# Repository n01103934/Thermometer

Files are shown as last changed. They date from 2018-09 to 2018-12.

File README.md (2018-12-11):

# Build Instructions

# Introduction
My project I am working with deals with reading temperature data from a temperature sensor. My sensor 
is called a TMP006 IR Temperature Sensor that can measure the temperature of any object without making direct contact with it.
It detects and absorbs the infrared energy from an object regardless of how hot or cold it is. I plan on storing 
my temperature data from my sensor to the Firebase database where all my data is stored. The reason why I chose this
project is because I was interested in the idea of reading an object's temperature data from the sensor just by pointing my finger
directly close to it. Here is a system UML diagram below to show you how my hardware will send data from my Raspberry Pi 3 to my database.
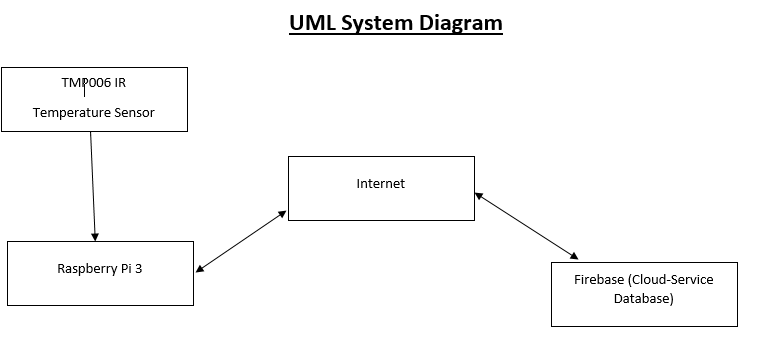
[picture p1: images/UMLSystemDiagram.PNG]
UML Diagram


# Bill of Materials/Budget
The total cost of my budget is $131.55 which is below the maximum limit of $150. I did not order any of my hardware materials online instead I went to local electronic stores such as Canada Computers and Creatron Inc. They had everything I needed in my budget including Raspberry Pi 3 kit, TMP006 IR Temperature Sensor, SD Card, USB to Ethernet Adapter, etc. I also included where I got my parts from the links in my budget. Here is a image below to show you my budget and all the materials I used for my project.
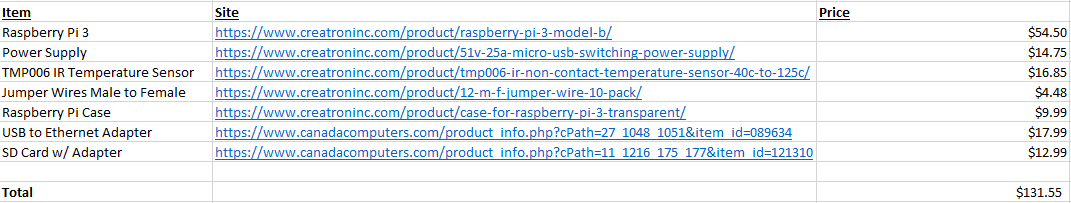
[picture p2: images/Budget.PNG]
Budget


# Time Commitment
The project did not take me long to complete because I got my parts ahead of time and started working on it as soon as possible.
However, their was still alot of time and commitment put in setting up my Raspberry Pi 3 and changing the default address to the
address you are assigned as well as reading data from the sensor. If you got all your materials then it would take you about 3 to 5 weeks to complete the project as long as you follow the steps of building it. Their are electronic stores that lucky have what you need such as Creatron Inc and Canada Computers. Once you acquired the parts start setting up your Raspberry Pi 3 which took almost a week at the lastest for me to set it up. After that then solder the header pins with the sensor to make a connection to it and the Raspberry Pi 3. Then, test the sensor and see if it can read data by running the python program for the sensor's library and it should be able to display the temperature readings on the output just by pointing finger close to the sensor. Overall, it took alot of time and commitment inorder to finish this project and put it all together for the next term.

# Mechanical Assembly
Before, you connect your sensor to Raspberry Pi 3 you need to get header pins in order for your Raspberry Pi 3 to detect it. I provided 
a link to show you where you could get them for your sensor incase you don't already have one.  
https://www.digikey.ca/product-detail/en/omron-electronics-inc-emc-div/XG8T-0231/XG8T-0231-ND/1829453?productid=1829453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

This open-sourced adafruit website will help you connect the TMP006 IR Temperature Sensor with the Raspberry Pi 3 or BeagleBone Black.
https://learn.adafruit.com/tmp006-temperature-sensor-python-library/hardware

Firstly, you need to connect a jumper wire from the 3.3V pin of the Raspberry Pi 3 to first pin(VCC) on my sensor. Secondly, the GND pin on Raspberry Pi 3 connects another jumper wire to the second pin(GND) of my sensor. After, connect a third jumper wire from SDA pin of Raspberry Pi 3 to the third pin(SDA) of my sensor. Then, the SCL pin of Raspberry Pi 3 connects with the fourth pin(SCL) of my sensor. The next link will give you information on how to change your sensor's default address which is 0x40 to another one ranging from 0x41 to 0x47. https://learn.adafruit.com/infrared-thermopile-sensor-breakout/assembly-and-wiring

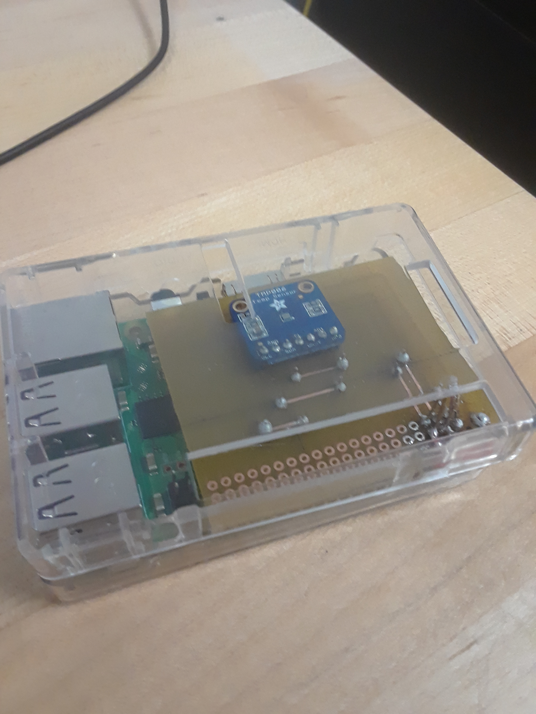
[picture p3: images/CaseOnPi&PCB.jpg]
PCB in Case


# PCB / Soldering
I made a fritzing file in my repository to create my own custom PCB just by following my breadboard and schematic
connections to do the same for the PCB. The file is called Thermometer Circuit Diagram.fzz in my github repository. 
https://github.com/n01103934/Thermometer

Here are images below to view my breadboard, schematic, and pcb diagrams for my project.
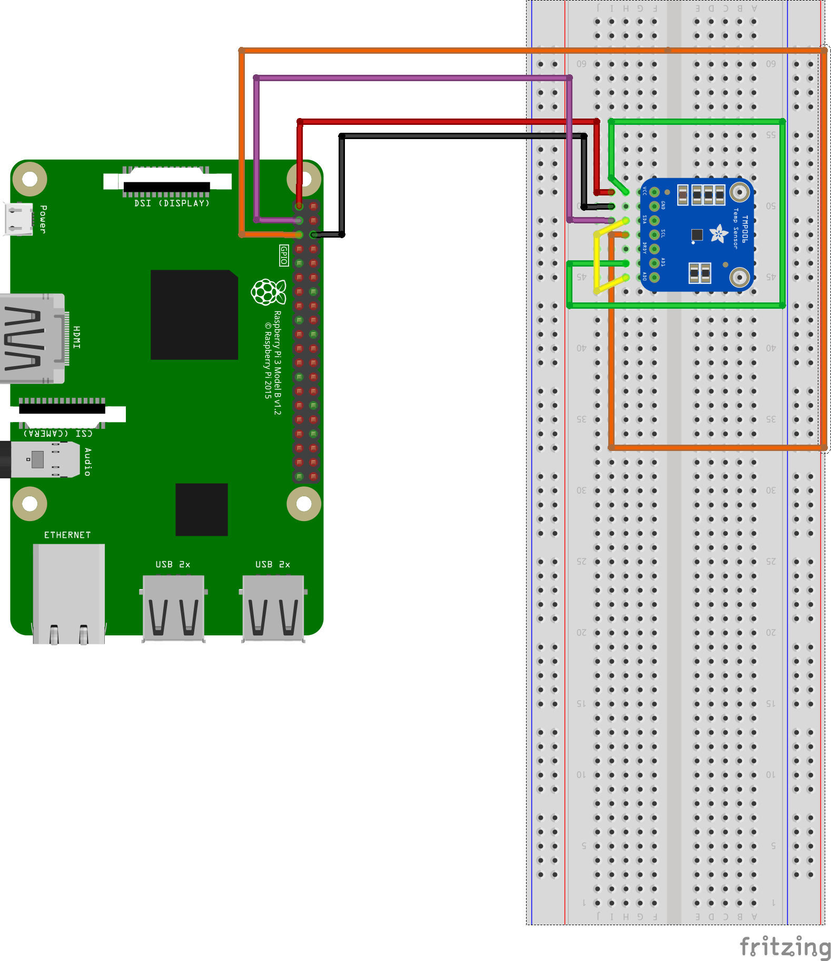
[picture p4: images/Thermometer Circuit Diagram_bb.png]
Breadboard

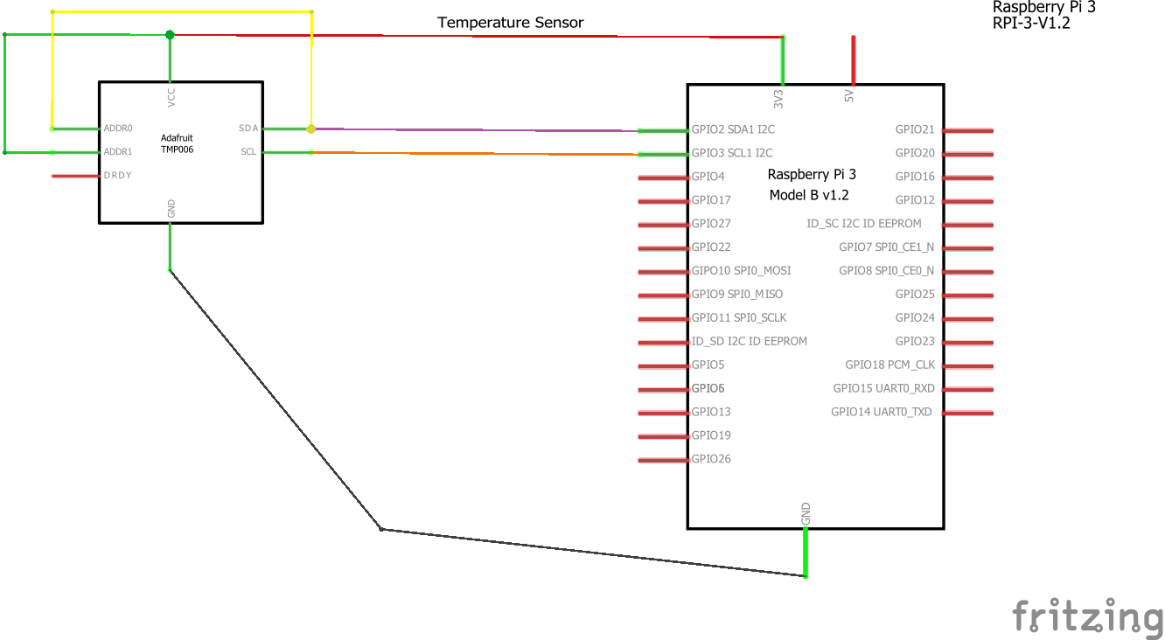
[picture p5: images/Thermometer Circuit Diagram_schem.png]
Schematic

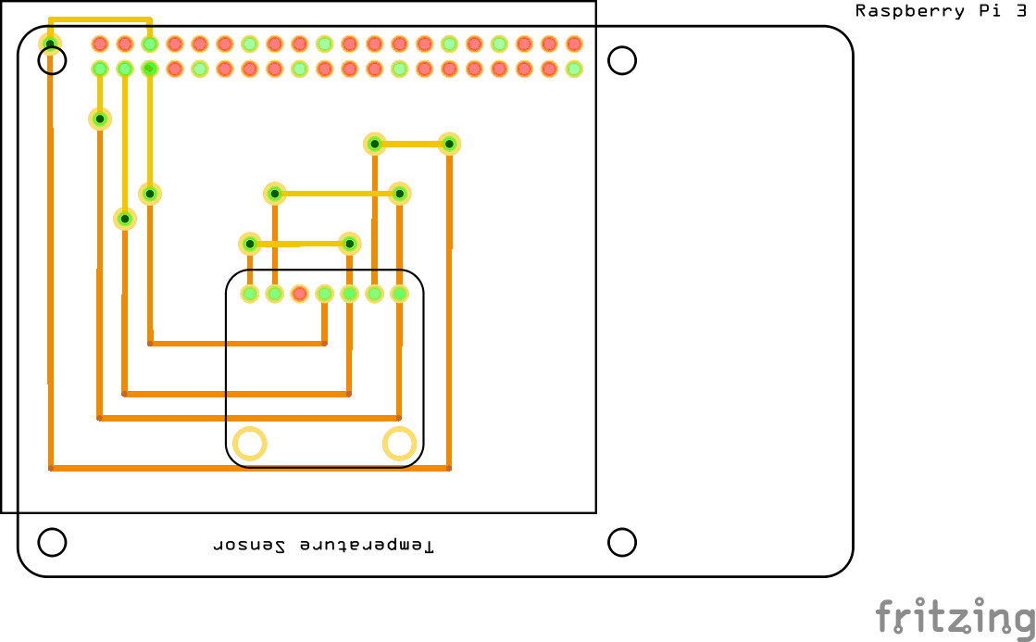
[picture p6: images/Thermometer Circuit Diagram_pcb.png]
PCB


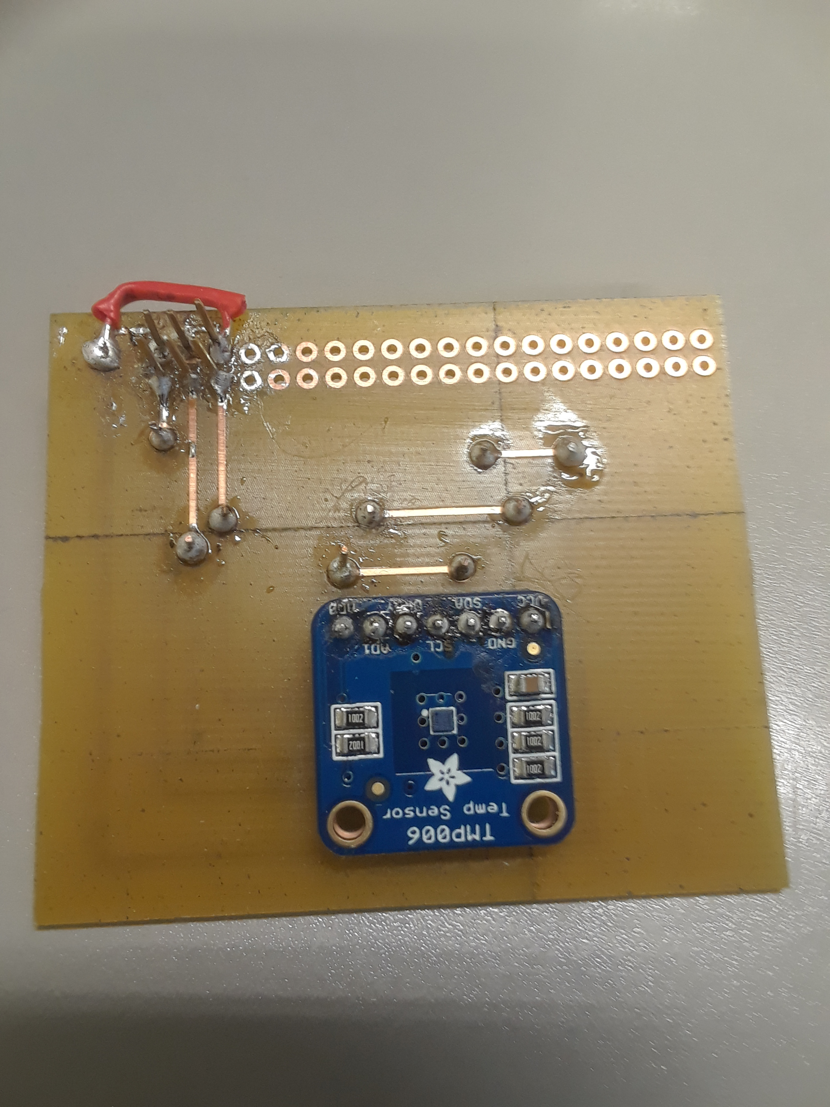
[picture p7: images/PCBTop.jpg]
PCB Top

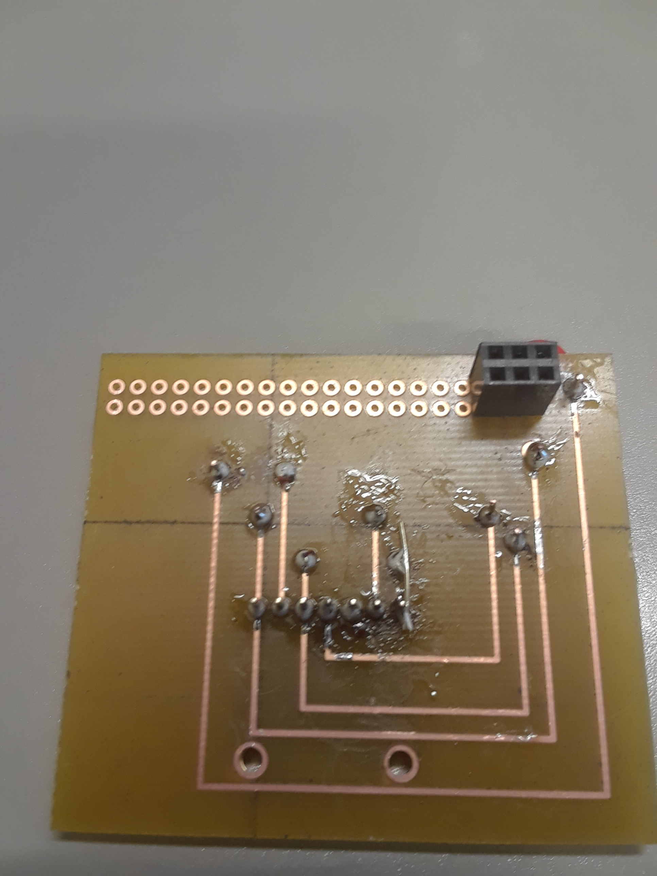
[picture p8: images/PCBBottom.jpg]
PCB Bottom


Additionally, I emailed the prototype lab my gerber files by exporting them from my fritzing project and got my board 
the next day. Then, I started soldering my via traces on my custom PCB and connected my header pins to the board. 
After, I soldered my header pins on sensor to my PCB board from the top to bottom and I connected the header socket to 
my board as well. I had to solder a wire connecting from the GND pin to my via trace connected to ground in order for my Raspberry Pi 3 to have a solid connection with my sensor. Finally, I connected the PCB to my Raspberry Pi 3, powered it on, ran the sudo i2cdetect -y 1 on cmd
terminal and I got my I2C address (0x46) displayed on the output for my sensor. 

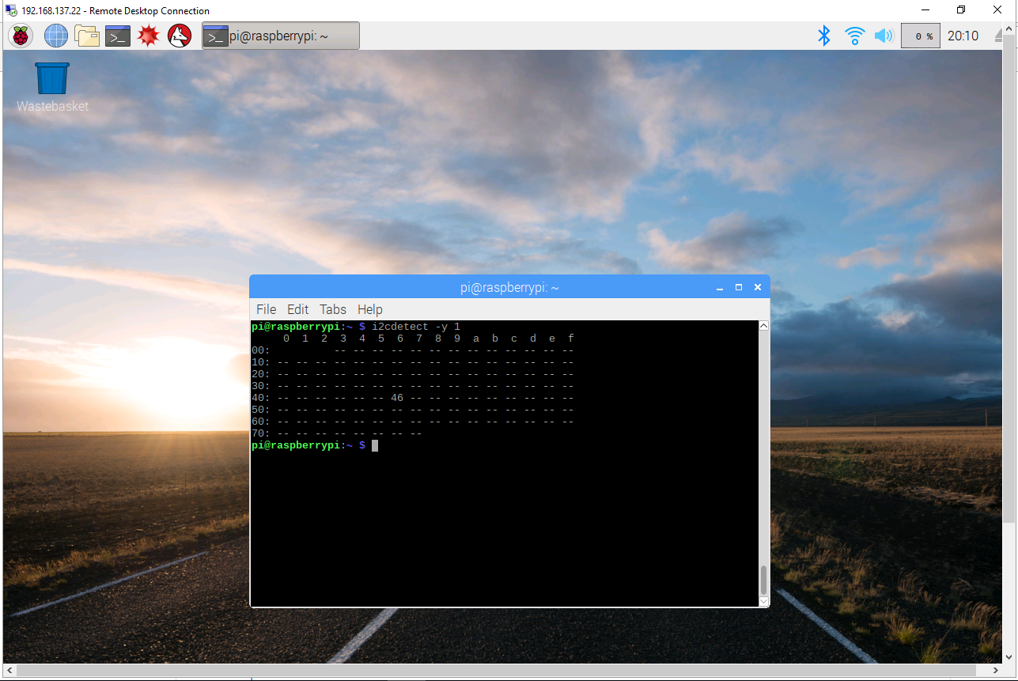
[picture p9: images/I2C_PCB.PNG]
I2COnPCB


# Power Up
First you need to download the operating system of Pi and format the micro SD card using the SD card reader included with 
the card to upload the Pi image to the Raspberry Pi 3. Here is a very useful blog that I followed step by step to upload my 
image to Raspberry Pi 3 as well as basic setup. https://github.com/six0four/StudentSenseHat/blob/master/cribpisdcard.md

Once you installed the operating system and got the image uploaded to Raspberry Pi 3, insert the SD card into the slot at the 
bottom of Pi, and boot it up with the power supply. If you are booting the Raspberry Pi 3 for the first time then you will have 
the option to change the default username and password to what ever suits you or you can leave it the same. The default username 
and password for every Raspberry Pi is always pi and raspberry unless a user changes it. Everything you need to know about the basic
setup of the Raspberry Pi is from the first link provided above just follow the instructions and your Pi should be ready. Some commands
to consider using for updating your Raspberry Pi 3 are sudo apt-get update and sudo apt-get dist-upgrade for installing packages to their latest versions for Pi. You need to make sure that I2C is enabled on the Raspberry Pi in order to use cmds like i2c detect for displaying the address of your sensor. In order to do that go to the Raspberry Pi configuration from start menu or type in terminal sudo raspi-config, then go to Interfaces and click on the I2C option to enable it if it hasn't already been enabled yet. 

Here is an image below to demonstrate me powering up my Raspberry Pi 3 with PCB connected to it.
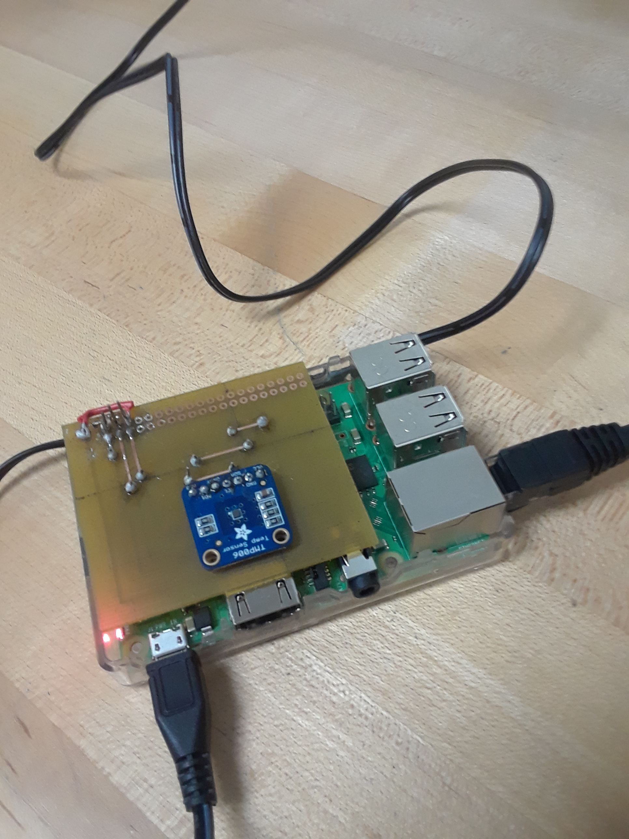
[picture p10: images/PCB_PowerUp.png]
PCB Powerup

 
# Unit Testing
In order to test whether or not the sensor is connected to the Raspberry Pi 3 properly you need to
open up a terminal on Pi and issue the command sudo i2cdetect -y 1 to list all the I2C addresses connected to the
Raspberry Pi 3. Here is an image below to show you my I2C address shown in the output screen.

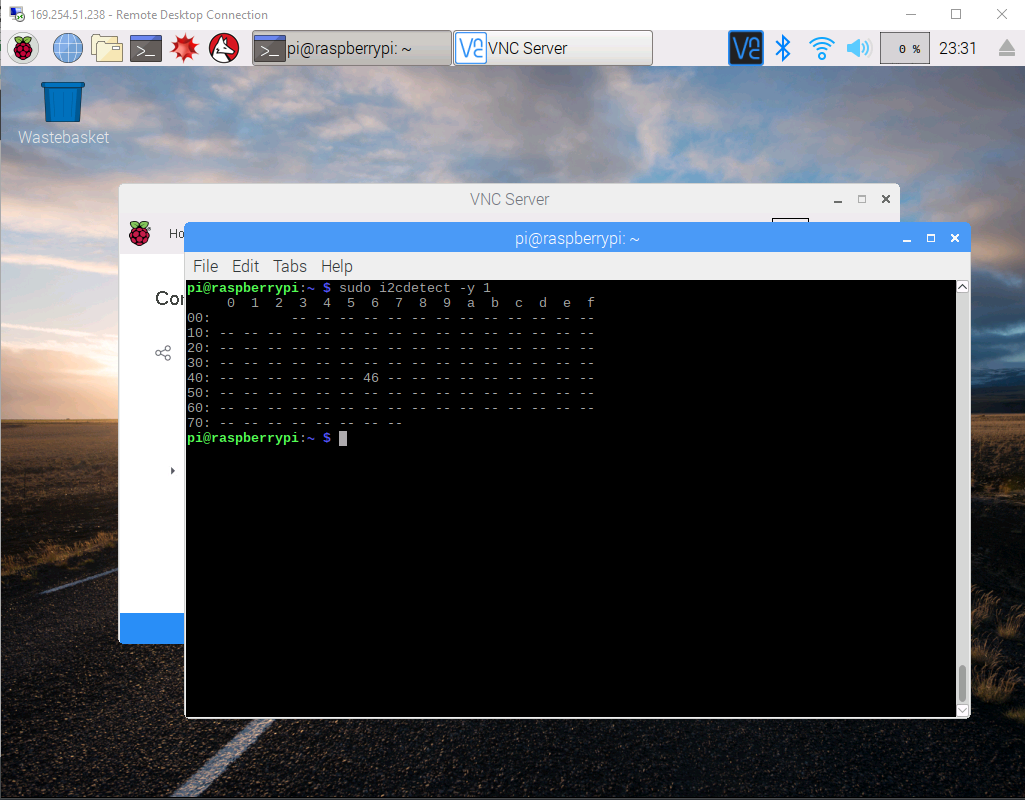
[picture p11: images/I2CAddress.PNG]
I2C Address


Additionally, once you see your address listed on the output now we can test the sensor by running
the python program from adafruit website. Follow the instructions on the adafruit website to install the python library
into Raspberry Pi 3 to run the simpletest.py that came with adafruit library for reading data from the sensor. The program
can be found in my github repository called simpletest.py and to compile/run it type in sudo python simpletest.py. This command 
will not only compile it but run the python program if there are no errors in the file and after entering it the program will
execute to display the temperature readings every second. 

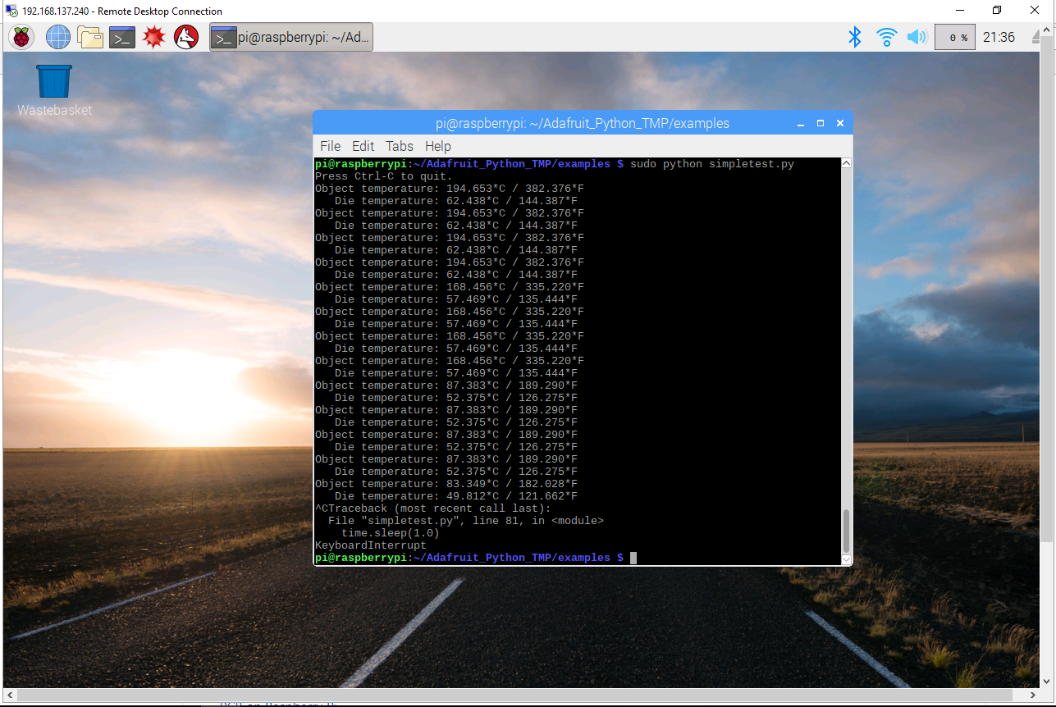
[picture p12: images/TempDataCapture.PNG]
Sensor Data


I have provided a link below to the open-sourced adafruit website which will show you step by step how to make the sensor read data by running the python program in terminal. https://learn.adafruit.com/tmp006-temperature-sensor-python-library/software 

# Production Testing
When the python program ran successfully, it displayed the temperature from the sensor itself 
and object temperature just by pointing my finger towards it. The temperature readings prints
out every second and change based on me putting my hand close to it and far from it. 
The program is running on an infinite loop so you don't need to keep running it again and again
to see if the temperature values are changing. 

# Reproducible
Yes

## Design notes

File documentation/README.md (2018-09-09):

---
csl: apa.csl
bibliography: RPiCitations.bib
---

Internet of Things Project
==========================

Projects website: http://six0four.github.io/StudentSenseHat

Table of Contents
=================

1.  [This File](#this-file)

2.  [References (generated when this file is
    exported)](#references-generated-when-this-file-is-exported)

This File
---------

This is a demonstration of a MarkDown (.md) README file.

Start editing this file by first installing Pandoc:
https://github.com/jgm/pandoc/releases/download/1.16.0.2/pandoc-1.16.0.2-windows.msi

Second, install Texts: http://www.texts.io/Texts-1.3.2.msi

Now you can open README.md using Texts and modify it. You can also export a .pdf
from the .md.

Ctrl-K can be used to modify Table of Contents entries/links, note that if a
Table of Contents is not created in the .md file it can be generated during the
export to .pdf process.

Ctrl-Shift-R can be used for adding citations. A citation example is for the
publication that we have referred to in our proposals where visiting the DOI
link below provides a page where a citation can be downloaded in the BibTex
format. This .bib bibliography file can then be added to this file. Next the
style .csl can be downloaded from https://www.zotero.org/styles/apa [@6894583]
\<- this will become (Segura-Garcia, Felici-Castell, Perez-Solano, Cobos, &
Navarro, 2015) plus the following entry will be added to the References when
this file is exported to .pdf which also triggers the installation of XeLaTeX:

Segura-Garcia, J., Felici-Castell, S., Perez-Solano, J. J., Cobos, M., &
Navarro, J. M. (2015). Low-cost alternatives for urban noise nuisance monitoring
using wireless sensor networks. *IEEE Sensors Journal*, *15*(2), 836–844.
<https://doi.org/10.1109/JSEN.2014.2356342>

Regarding an example for the Fall 2017 session I use the below to generate the
content which appears in the References List when the pdf is exported.

Current product APA citation: [@TouchScreen]

Existing research IEEE paper APA citation: [@7513420] 
Light Sensor [@1459018]  
Water Sensor [@5444949]  
WebCam [@6311360]  
MicroPhone [@7906891]  
Time of flight [@7590295]  
Ultrasonic sensor [@6626258]  
infra red sensor [@6626258]  
fingerprint reader [@5655244]  
RFID [@5655244]  
servo [@7345541]  
Analog Feedback Servo [@7345541] 

\pagebreak

References (generated when this file is exported)
-------------------------------------------------

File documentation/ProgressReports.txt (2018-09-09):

Progress reports are to be posted on the weeks that they are due and are to include:
•	A description of recent project activities with reference to the project schedule.
•	Current progress in meeting the objectives of the project as defined in the approved proposal.
•	Description of any problems/opportunities encountered and modifications being made to address them.
•	Financial updates on the use of project funds, along with a brief commentary where significant variances exist from the budget.
•	Links to repository copies of any published media coverage, promotional materials, reports, documents or publications arising from the project.

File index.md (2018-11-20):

# Nov 20 2018
This week I put my Raspberry Pi 3 and PCB into a protected case to be used for protection against hard surfaces. The case is the right size that can fit both the Raspberry Pi and PCB altogether. My project is already suitable for the Computer Systems Project Course that I take next semester because I have finished building my final hardware. I am already prepared for next week's presentation because my hardware project is completed fully under the desired time this semester ends. I am still using the same hardware materials in my project as stated in my Proposal. Based from my Project Schedule I am on track because I have completed the enclosure by this week and I am now preparing my powerpoint presention slides for next week. My budget is fine all my materials are in good condition so I don't have to buy anymore for my project. Their is a link below this discussion on my Rapberry Pi 3 & PCB inside my protected case.  

[Case for Pi & PCB](https://raw.githubusercontent.com/n01103934/Thermometer/master/images/CaseOnPi%26PCB.jpg)

# Nov 13 2018
This week I demonstrated my functional hardware can read data from my sensor and display the results on the screen. Firstly, I was able to figure out how to connect to my Raspberry Pi using Remote Desktop Connection and issue the i2c detect command to see my address was working on my PCB board successfully. My project is going well the PCB is powered on right and I can read temperature data from my sensor every second just by moving my finger close to it. My financial status is good my hardware was not damaged during production and testing which will not delay time creating my project. I am still using the same materials for building my capstone project as stated in my proposal. Furthermore, I am still on track based from my project schedule because I have completed by this week powering up my Raspberry Pi with PCB to show that I can read data from my sensor. There are links at the bottom of this weeks discussion to show proof of powering on my developmental platform with PCB attached to it, I2C address and reading data from my sensor.

[PCB Powered Up](https://raw.githubusercontent.com/n01103934/Thermometer/master/images/PCB_PowerUp.png)

[I2C on PCB](https://raw.githubusercontent.com/n01103934/Thermometer/master/images/I2C_PCB.PNG)

[My Sensor's Data](https://raw.githubusercontent.com/n01103934/Thermometer/master/images/TempDataCapture.PNG)

# Nov 6 2018
This week I soldered my PCB for my TMP006 IR Temperature Sensor, Raspberry Pi 3 with the help of Vlad and Kelly in the prototype lab. Before my sensor was not picking up my address on the Raspberry Pi 3. However, I told Vlad the problem and we both troubleshooted the issue and found out the Ground and SDA pins were not picking up on multimeter. I had to strip both ends of a wire and connect it from the Ground pin on Raspberry Pi to my via trace connecting to GND pin for my Temperature Sensor from the top of the PCB. Then I had to connect another wire from Add1 to the via trace connecting to my SDA pin on the bottom of my PCB. Afterwards, my address is shown when I issue the I2C detect command the same way as I did using the breadboard and jumper wires for my connections. But this time I using the PCB for connecting my sensor to Raspberry Pi and I am getting the same results so I should now be able to get data from my Temperature Sensor. I am currently testing out if my sensor can detect temperature data and readings from any object close to it in order to display it on the terminal. My project has not changed I am still using both my Temperature Sensor and Raspberry Pi as stated in my Proposal. I am still on track based from my project schedule because I have completed the PCB Soldering this week and now I am working on the milestone for next week. I still need to figure out how to get my data from sensor by next week but other than that the project is going well. My financial status is good I am using the same materials in my budget but it could change if my materials are damaged from testing it. There are links below this weeks discussion to my soldered PCB from the top to bottom and on the Raspberry Pi below to show what I did for this week.

[PCB Top Soldered](https://raw.githubusercontent.com/n01103934/Thermometer/master/images/PCBTop.jpg)

[PCB Bottom Soldered](https://raw.githubusercontent.com/n01103934/Thermometer/master/images/PCBBottom.jpg)

[PCB on Raspberry Pi](https://raw.githubusercontent.com/n01103934/Thermometer/master/images/PCBPi.jpg)

# Oct 30 2018
This week I will have designed a PCB for my TMP006 IR Temperature Sensor and Raspberry Pi 3. I should get it soon from the prototype lab to be able soldering it for next week. Based on my project schedule I am still on track as long as I get my PCB designed and soldered by next week. My project has not changed based from my proposal I am still using the same materials from before to build it. My financial update is good I am still under budget and most of the stuff I need I already have so their is no need to buy more materials for my project. I have included the fritzing file for my project in my respository to look at how I designed the pcb. Here are links at the bottom of this weeks discussion on my design files for breadboard, schematic, and pcb diagrams.

[My breadboard diagram](https://raw.githubusercontent.com/n01103934/Thermometer/master/images/Thermometer%20Circuit%20Diagram_bb.png)

[My schematic diagram](https://raw.githubusercontent.com/n01103934/Thermometer/master/images/Thermometer%20Circuit%20Diagram_schem.png)

[My pcb diagram](https://raw.githubusercontent.com/n01103934/Thermometer/master/images/Thermometer%20Circuit%20Diagram_pcb.png)

# Oct 23 2018
This week I soldered my TMP006 IR Temperature sensor, connected wires from my sensor to broadcom development platform and have completed getting my sensor to detect my I2C address on Raspberry Pi 3. I researched my sensor's pin layout to determine how to change my default I2C address from (0x40) to (0x46) for my temperature sensor. I found out to get my I2C address you have to connect wires from Add0 to SDA and Add1 to VCC from my sensor connected to breadboard. I have provided links at the bottom of this weeks discussion for observing my breadboard circuit and I2C address from my sensor below.  Based on the project schedule I am on track because it shows that week eight I have to complete the breadboard milestone. Next week I have to design a PCB Board, I already emailed the prototype lab my gerber files of my circuit diagram in order to design one. The project has not changed I am still using the same materials like my TMP006 IR Temperature Sensor and Raspberry Pi 3 based from my Proposal.

[My breadboard circuit](https://raw.githubusercontent.com/n01103934/Thermometer/master/images/breadboard_circuit_diagram.png)

[My fritzing circuit](https://raw.githubusercontent.com/n01103934/Thermometer/master/images/Thermometer%20Circuit%20Diagram_bb.png)

[My sensor's I2C address](https://raw.githubusercontent.com/n01103934/Thermometer/master/images/I2CAddress.PNG)

# Oct 16 2018 
This week I will solder my header pins for my temperature sensor on the breadboard and connect them with my developmental platform.

# Oct 9 2018
I have my parts with me and working on fritzing my connections on breadboard.

# Oct 2 2018
Proof of purchase is due and here are pictures of my parts that I ordered at store.
[pictures of my parts](https://raw.githubusercontent.com/n01103934/Thermometer/master/images/parts.png)

# Sept 25 2018
Worked on budget for project and I have completed it. I have provided a excel document of the budget in my Github respository.

# Sept 18 2018
Worked on project schedule and submitted it. I provided a microsoft project document of the schedule in my Github respository.

# Sept 11 2018
Worked on proposal and submitted it. I also provided a word document and pdf of proposal in my Github respository.

# Sept 4 2018
Worked on and completed lighting up an LED on the Raspberry Pi 3.

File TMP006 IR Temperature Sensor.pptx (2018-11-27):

## TMPoo6 IR Temperature Sensor

Malin Lomax
CENG317
11/27/2018

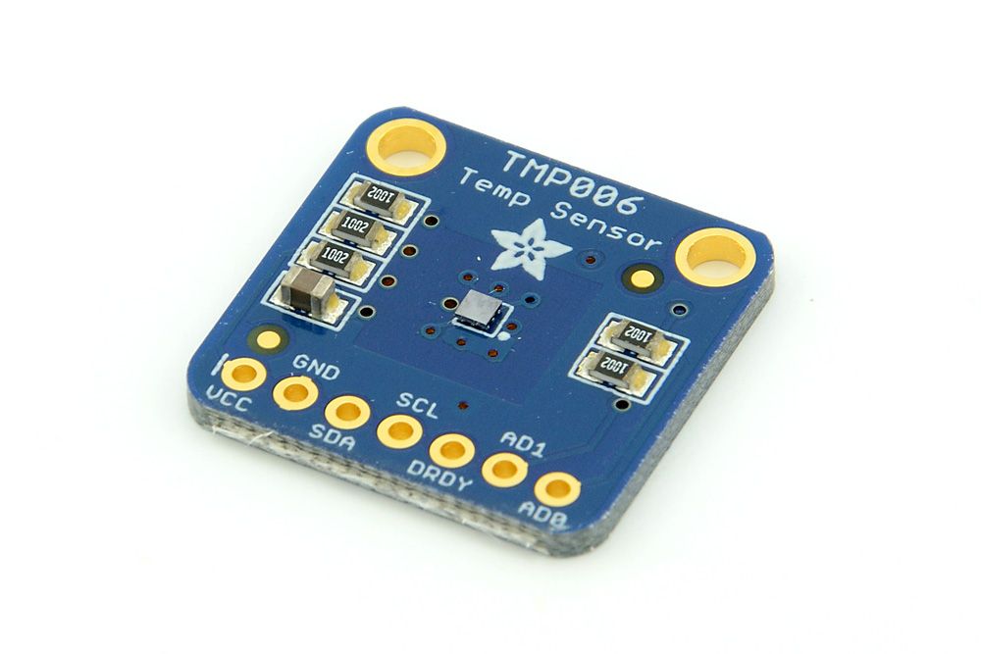
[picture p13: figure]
Image result for TMP006 IR Temperature Sensor

## Proposal

- TMPoo6 IR Temperature Sensor is a sensor that can measure the temperature of any object without making contact with it.
- It detects and absorbs the infrared energy of an object regardless of how hot or cold it is.
- The address that I am currently using this semester for my sensor is 0x46.
- I plan on storing my temperature readings from my sensor to the Firebase database where all my data is stored.
- My Proposal has changed I am now using the PCB to connect my sensor to Raspberry Pi 3 instead of jumper wires.

## Budget

- Raspberry Pi 3 $54.50
- Power Supply $14.75
- TMP006 IR Temperature Sensor $16.85
- USB to Ethernet Adapter $17.99
- SD Card w/ Adapter $12.99
- Ethernet Cable $0.00
- Total Cost $131.55
- My Budget has not changed, I am still using the same materials for building my capstone project.

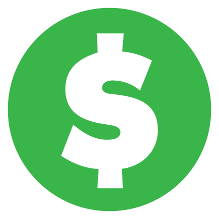
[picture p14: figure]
Image result for dollar sign

## Schedule

- Based on my project schedule I am on track because this week I am presenting my project and my hardware is completed on time for next semester.

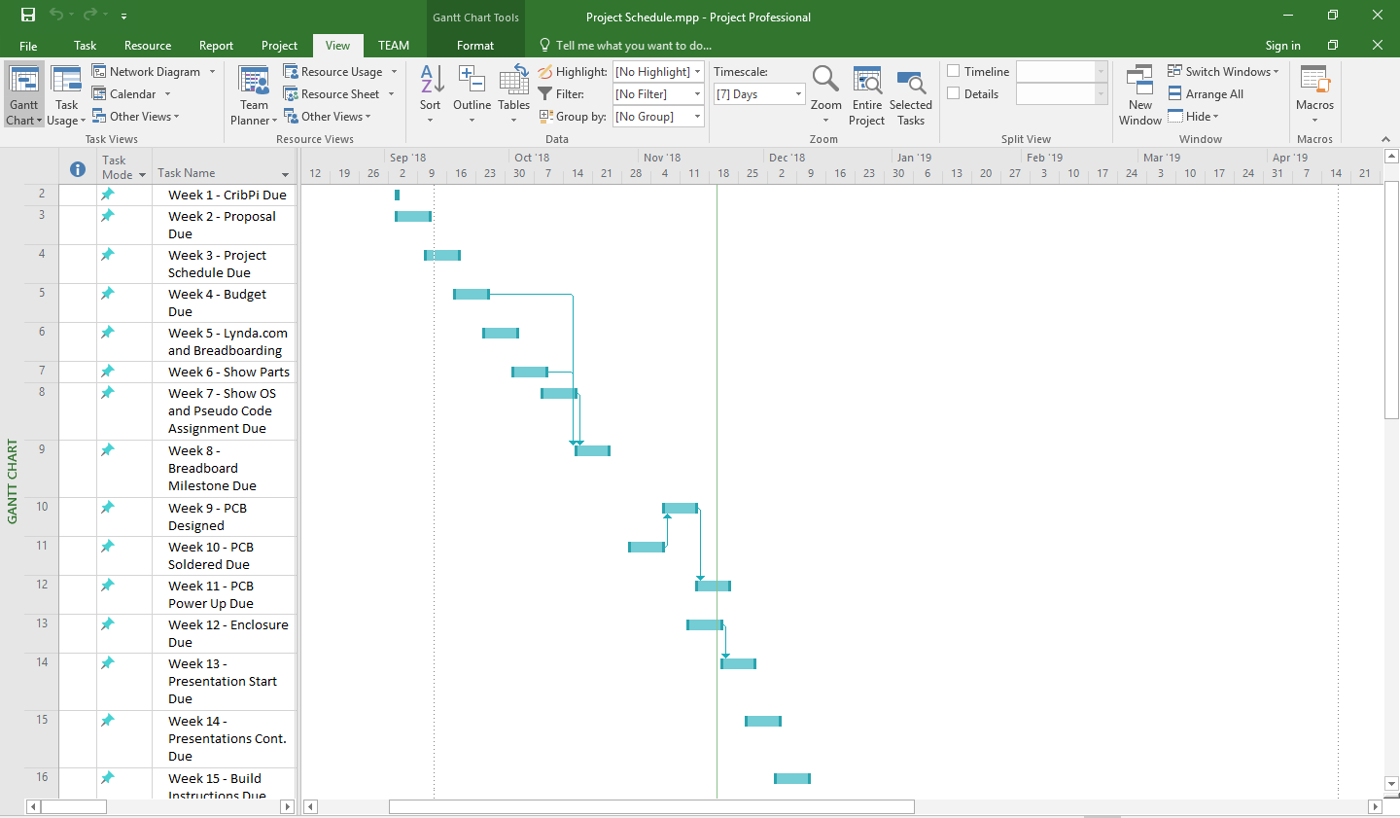
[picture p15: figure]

## Final Hardware

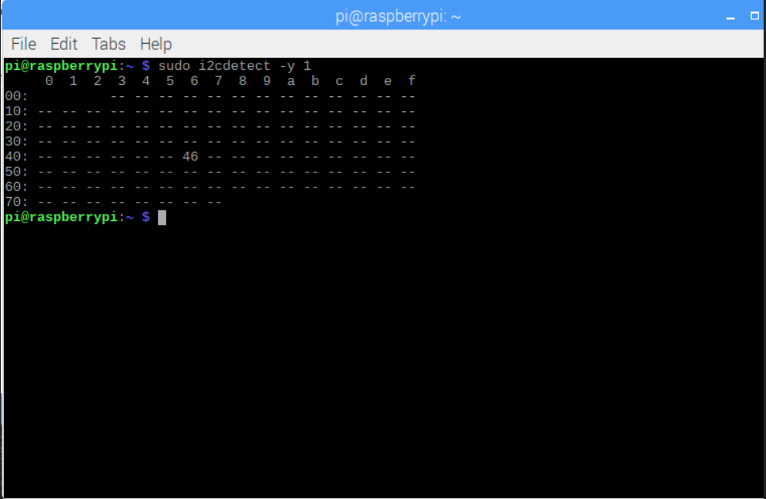
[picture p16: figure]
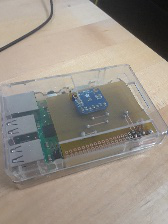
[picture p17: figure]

## Reading Data from Sensor

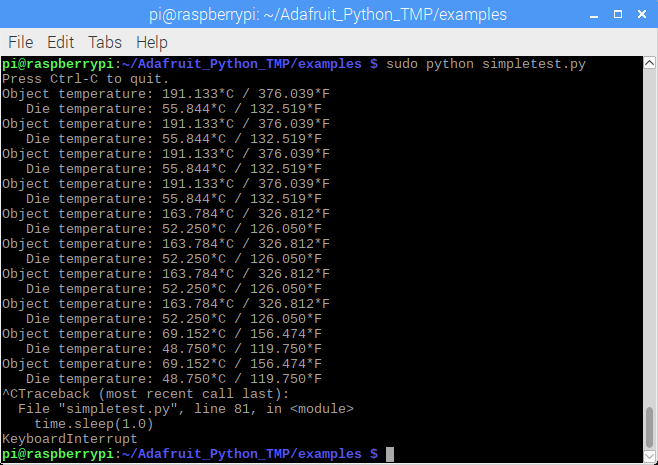
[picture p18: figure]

- The program I used was written in python to read data from my sensor and I sourced it from Adafruit. It reads data and prints out temperature readings from my sensor every second.
- I changed the default constructor address to my sensor’s address in the python program from 0x40 to 0x46.
- Object Temperature is the temperature data read from something that is hot right next to the sensor such as a person’s finger in both Celsius and Fahrenheit.
- Die Temperature is the temperature data read from the sensor itself like how hot the chip is in Celsius and Fahrenheit.

## Courses Applied in Project

- CENG215 Digital Interface Systems – Introduction to Sensors. Building circuits and reading data from sensors.
- CENG216 Software Engineering – Creating Gantt Charts to monitor the progress of individual activities.
- CENG252 Embedded Systems – I2C, SDA, Microcontroller's, Creating Projects on Raspberry PI, etc.
- WRIT220 Technical Workplace Writing Skills – Writing Progress Reports on blog to show updates on project.
- TECH153 Technical C – Introduction to Raspberry Pi 3, UNIX, Remote Desktop Connection and making an LED on Raspberry Pi blink.

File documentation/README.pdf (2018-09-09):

## Internet of Things Project

Projects website: http://six0four.github.io/StudentSenseHat

## Table of Contents

1. This File
2. References (generated when this file is exported)

### This File

This is a demonstration of a MarkDown (.md) README file.

Start editing this file by first installing Pandoc: https://github.com/jgm/pandoc/releases/download/1.16.0.2/pandoc-1.16.0.2-windows.msi

Second, install Texts: http://www.texts.io/Texts-1.3.2.msi

Now you can open README.md using Texts and modify it. You can also export a .pdf from the .md.

Ctrl-K can be used to modify Table of Contents entries/links, note that if a Table of Contents is not created in the .md file it can be generated during the export to .pdf process.

Ctrl-Shift-R can be used for adding citations. A citation example is for the publication that we have referred to in our proposals where visiting the DOI link below provides a page where a citation can be downloaded in the BibTex format. This .bib bibliography file can then be added to this file. Next the style .csl can be downloaded from https://www.zotero.org/styles/apa (Segura-Garcia, Felici-Castell, Perez-Solano, Cobos, & Navarro, 2015) <- this will become (Segura-Garcia, Felici-Castell, Perez-Solano, Cobos, & Navarro, 2015) plus the following entry will be added to the References when this file is exported to .pdf which also triggers the installation of XeLaTeX:

Segura-Garcia, J., Felici-Castell, S., Perez-Solano, J. J., Cobos, M., & Navarro, J. M. (2015). Low-cost alternatives for urban noise nuisance monitoring using wireless sensor networks. IEEE Sensors Journal, 15(2), 836–844. https://doi.org/10.1109/JSEN.2014.2356342

Regarding an example for the Fall 2017 session I use the below to generate the content which appears in the References List when the pdf is exported.

Current product APA citation: (Fried, 2017)

Existing research IEEE paper APA citation: (Gao, Arcos, & Nathan, 2016) Light Sensor (Kokhanovsky, Aoki, Hachikubo, Hori, & Zege, 2005)
Water Sensor (Abou-Arkoub, Thorn, & Bousbaine, 2010)
WebCam (Battaglia & Iannizzotto, 2012)
MicroPhone (Gibbs, 2017)
Time of flight (Zsedrovits et al., 2016)
Ultrasonic sensor (Lee, Kim, Wang, Kim, & Baek, 2013) infra red sensor (Lee et al., 2013)
fingerprint reader (Clark et al., 2010)
RFID (Clark et al., 2010)
servo (Wu, Law, Mak, & Martins, 2016) Analog Feedback Servo (Wu et al., 2016)

1

### References (generated when this file is exported)

Abou-Arkoub, A., Thorn, R., & Bousbaine, A. (2010). Online validation of multiphase flowmeters using simple capacitance sensors. IEEE Transactions on Instrumentation and Measurement, 59(10), 2671– 2682. https://doi.org/10.1109/TIM.2010.2045554

Battaglia, F., & Iannizzotto, G. (2012). An open architecture to develop a handheld device for helping visually impaired people. IEEE Transactions on Consumer Electronics, 58(3), 1086–1093. https://doi.org/10.1109/TCE.2012.6311360 (https://doi.org/10.1109/TCE.2012.6311360)

Clark, P. C., Cook, G. R., Fisher, E. L., Fulp, J. D., Linhoff, V., & Irvine, C. E. (2010). New pathways in
identity management. IEEE Security Privacy, 8(6), 64–67. https://doi.org/10.1109/MSP.2010.183

Fried, L. (2017). PiTFT plus 480x320 3.5” tFT+Touchscreen for raspberry pi.; https://www.adafruit.com/product/2441.

Gao, S., Arcos, V., & Nathan, A. (2016). Piezoelectric vs. capacitive based force sensing in capacitive
touch panels. IEEE Access, 4, 3769–3774. https://doi.org/10.1109/ACCESS.2016.2591535

Gibbs, W. W. (2017). Build your own amazon echo - turn a pI into a voice controlled gadget [resources_Hands on]. IEEE Spectrum, 54(5), 20–21. https://doi.org/10.1109/MSPEC.2017.7906891

Kokhanovsky, A. A., Aoki, T., Hachikubo, A., Hori, M., & Zege, E. P. (2005). Reflective properties of natural snow: Approximate asymptotic theory versus in situ measurements. IEEE Transactions on Geoscience and Remote Sensing, 43(7), 1529–1535. https://doi.org/10.1109/TGRS.2005.848414

Lee, K., Kim, Y. S., Wang, Y., Kim, S., & Baek, K. H. (2013). A remote pointing device by using modulated iR signals with a 2-d striped pattern. IEEE Transactions on Consumer Electronics, 59(3), 699–704. https://doi.org/10.1109/TCE.2013.6626258

Segura-Garcia, J., Felici-Castell, S., Perez-Solano, J. J., Cobos, M., & Navarro, J. M. (2015). Low-cost alternatives for urban noise nuisance monitoring using wireless sensor networks. IEEE Sensors Journal, 15(2), 836–844. https://doi.org/10.1109/JSEN.2014.2356342

Wu, J., Law, M. K., Mak, P. I., & Martins, R. P. (2016). A 2- µW 45-nV/ #x221A;Hz readout front end with multiple-chopping active-high-pass ripple reduction loop and pseudofeedback dC servo loop. IEEE Transactions on Circuits and Systems II: Express Briefs, 63(4), 351–355. https://doi.org/10.1109/TCSII.2015.2504944 (https://doi.org/10.1109/TCSII.2015.2504944)

Zsedrovits, T., Peter, P., Bauer, P., Pencz, B. J. M., Hiba, A., Gozse, I., … Bokor, J. (2016). Feature article: Onboard visual sense and avoid system for small aircraft. IEEE Aerospace and Electronic Systems Magazine, 31(9), 18–27. https://doi.org/10.1109/MAES.2016.150129

2

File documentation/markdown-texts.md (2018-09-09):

Welcome to Texts!
=================

Texts is “rich editor for plain text”—you can write documents in visual
interface and they will be saved in plain text format with Markdown markup. This
document shows some styles available in Texts. Please feel free to edit it—a
fresh copy is always available via Help menu.

Inline Formatting
-----------------

To apply *emphasis* or **strong emphasis** press Control+I or Control+B and
type. Press again to turn it off.

Footnotes
---------

Notes can be placed anywhere[^1] in the source file (press Control+R to insert
one). When document is published to paper-oriented format (PDF or Word)
footnotes are displayed at the bottom of the corresponding page. E-book readers
usually display notes in popups.

[^1]: Yes, right here.

Hyperlinks
----------

Press Control+K to insert a hyperlink. It can be either literal URL
(<http://www.google.com/>) or have some [text](http://www.texts.io/). Click URL
with Control key pressed to open it in web browser.

Math
----

Formulas can be placed inline like $$E=mc^2$$ or in a separate paragraph, like
the following one. Standard LaTeX syntax is supported.

$$
\frac{n!}{k!(n-k)!} = \binom{n}{k}
$$

Code
----

Inline `code` gets monospaced font.

~~~~~~~~~~~~~~~~~~~~~~~~~~~~~~~~~~~~~~~~~~~~~~~~~~~~~~~~~~~~~~~~~~~~~~~~~~~~~~~~
Verbatim blocks use monospaced font as well and preserve line
breaks
~~~~~~~~~~~~~~~~~~~~~~~~~~~~~~~~~~~~~~~~~~~~~~~~~~~~~~~~~~~~~~~~~~~~~~~~~~~~~~~~

Press “Enter” key inside code block to insert a line break or “Shift+Enter” to
end code block.

Lists
-----

-   First bulleted item.

-   Second bulleted item.

Lists can be styled via menu, keyboard shortcut, or using autoformatting: type
minus and space for bulleted item or “1”, point and space for numbered item.
Press “Tab” to indent paragraph and create subitem, “Shift+Tab” to unindent.

1.  First numbered item.

2.  Second numbered item.

Tables
------

Press **Ctrl+Shift+L** to create a table, Ctrl+Alt+arrow keys to add more
columns or rows, Alt+Shift+arrow keys to move column or row. Here is a sample
table.

| **Features** | **Editable in Texts** | **Export to PDF** | **Export to HTML** |
|---|---|---|---|
| Basic Styles | Yes | Yes | Yes |
| Footnotes | Yes | Yes | Yes |
| Images | Yes | Yes | Yes |
| Tables | Yes | Yes | Yes |

Happy writing!
==============

Got a question? Visit <http://www.texts.io/support/>.

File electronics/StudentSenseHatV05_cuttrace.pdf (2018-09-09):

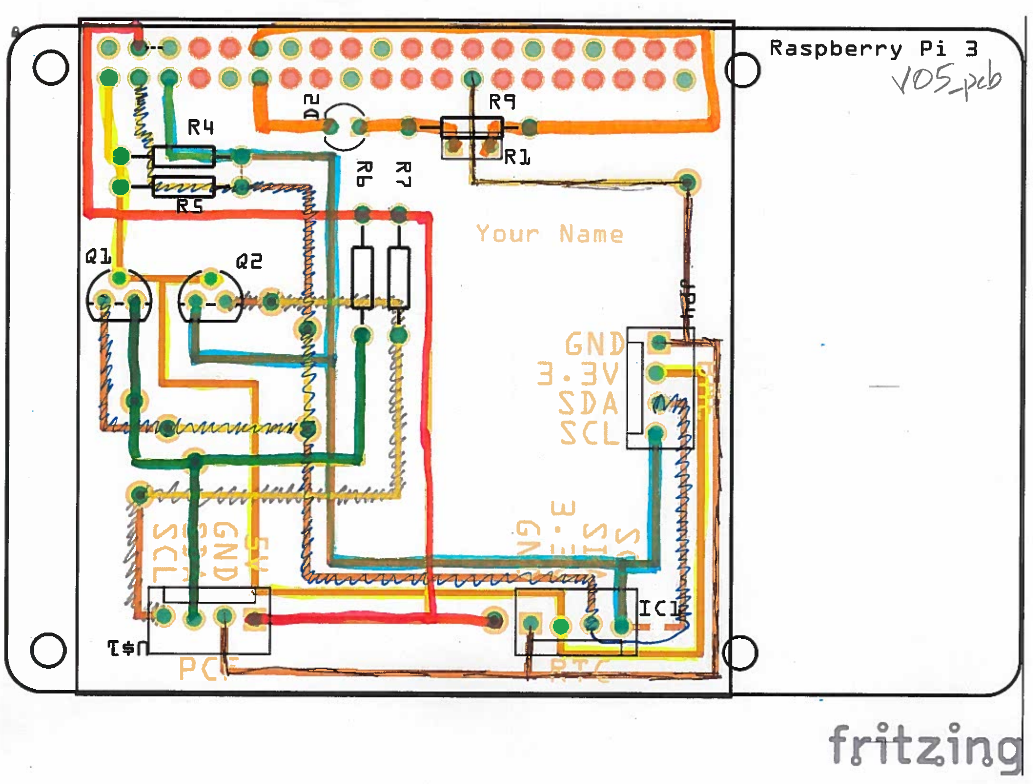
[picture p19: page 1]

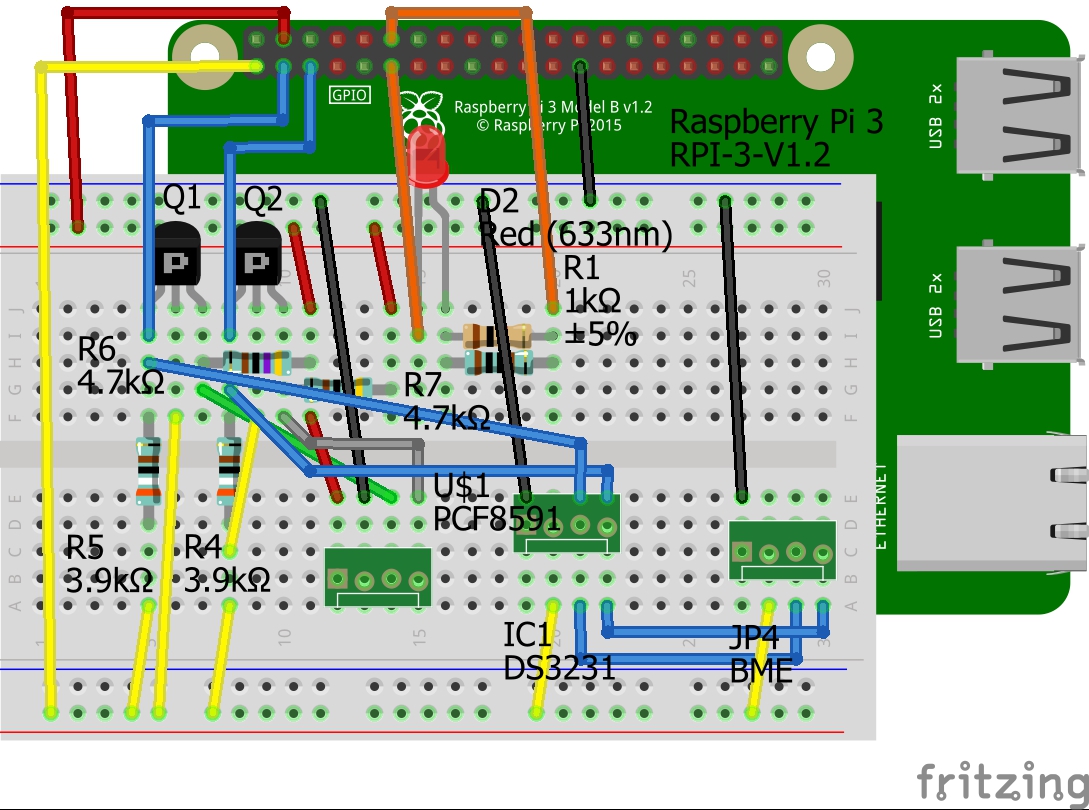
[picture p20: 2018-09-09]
electronics/StudentSenseHatV06_bb.jpg

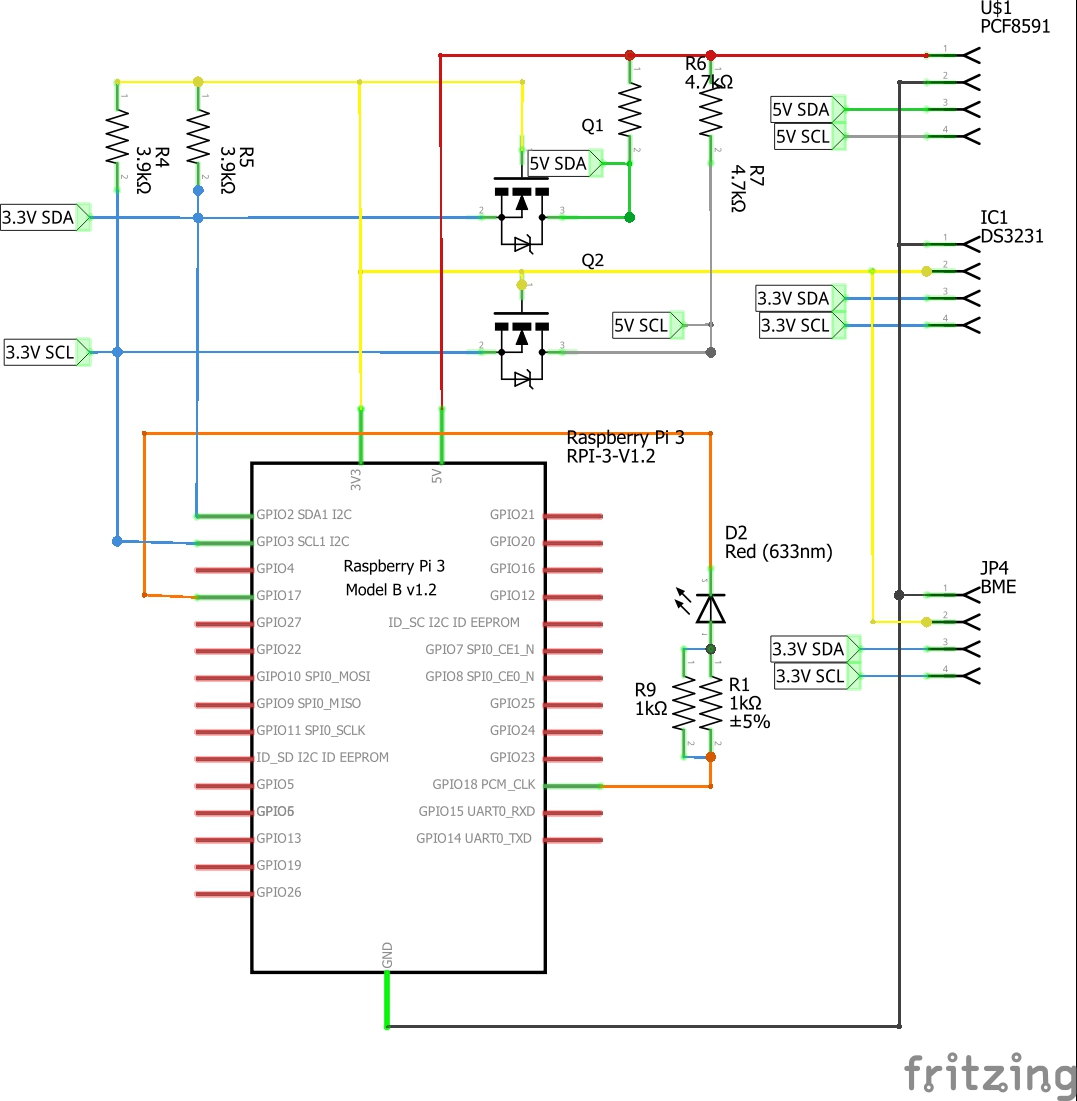
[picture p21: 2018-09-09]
electronics/StudentSenseHatV06_schem.jpg

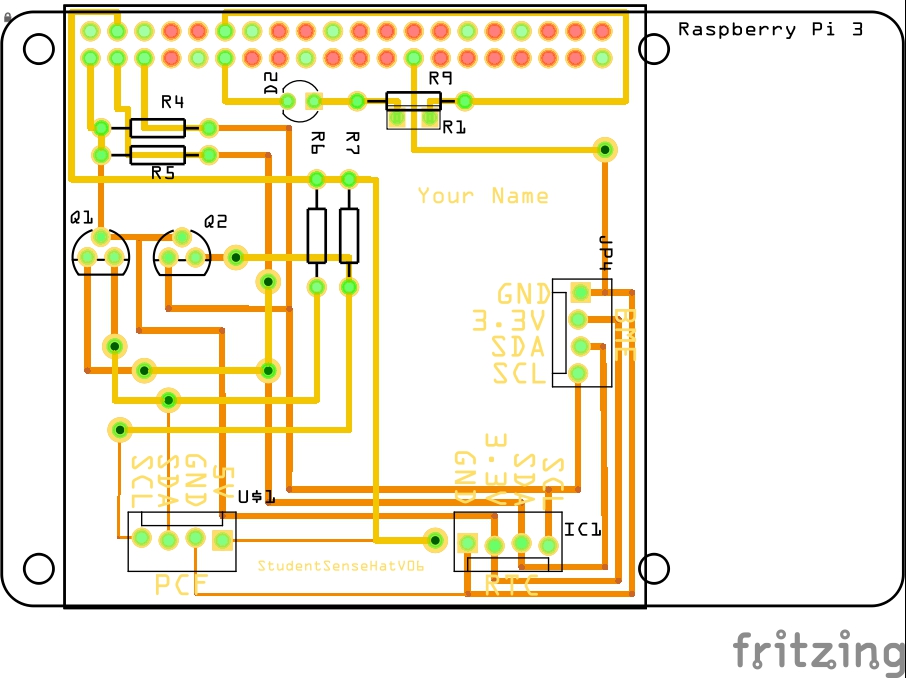
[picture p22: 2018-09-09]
electronics/StudentSenseHatV06_pcb.jpg

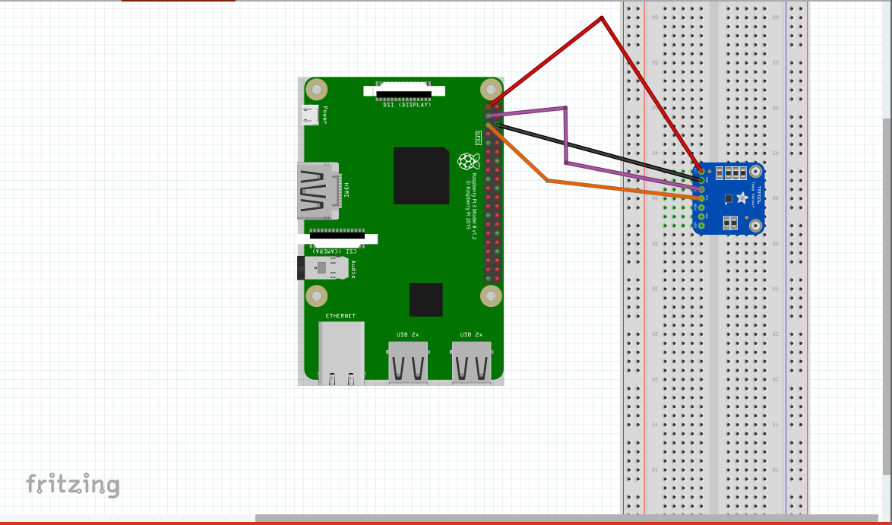
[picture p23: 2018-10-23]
images/Thermometer Circuit Diagram.PNG

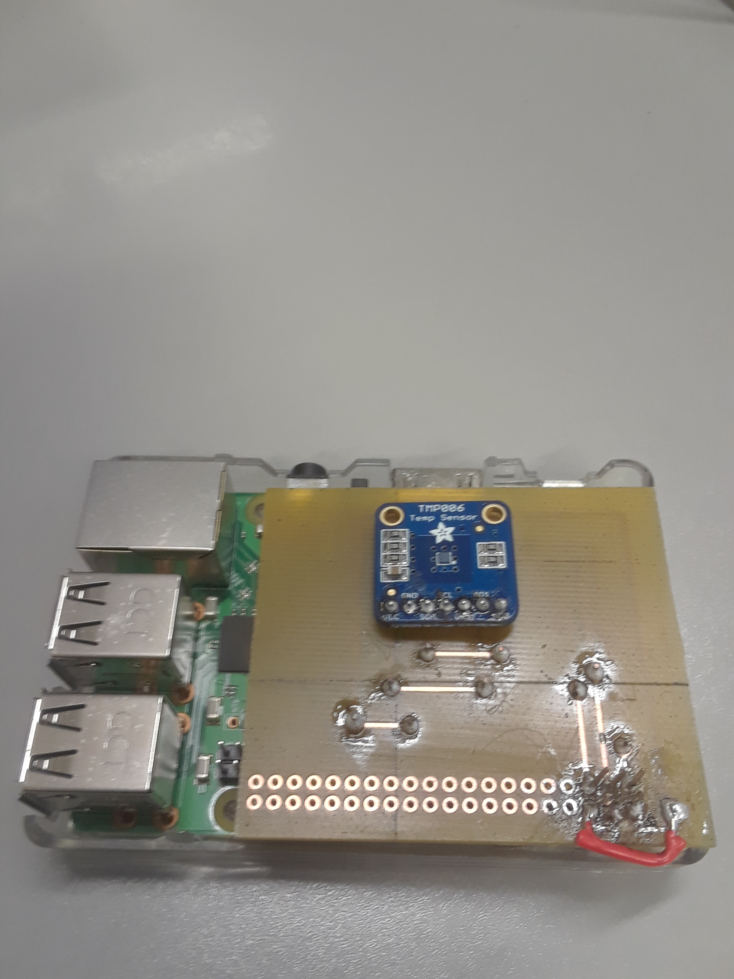
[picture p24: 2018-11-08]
images/PCBPi.jpg

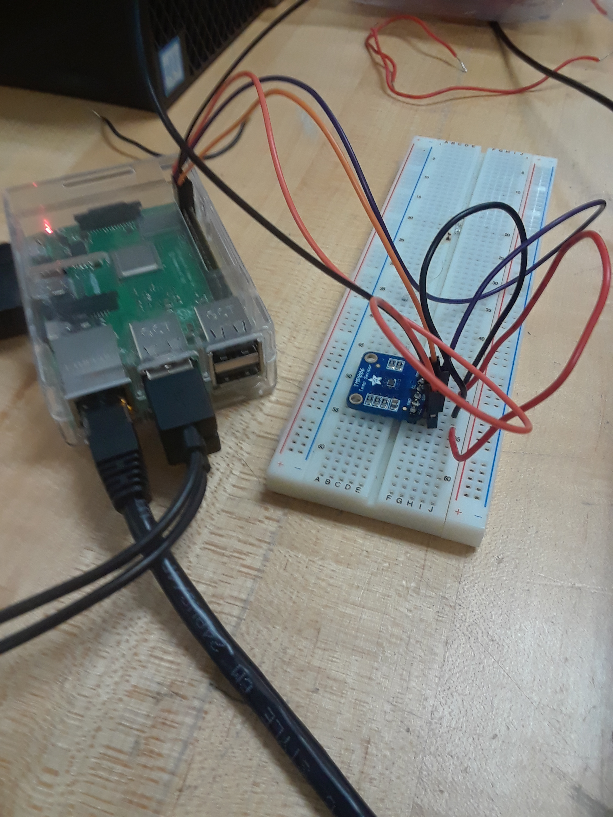
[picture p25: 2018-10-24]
images/breadboard_circuit_diagram.png

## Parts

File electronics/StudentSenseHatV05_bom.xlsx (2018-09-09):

Part | Description | Quantity | Package | Value | Supplier | Reference Number | Cost (1) | Cost (60) | Subtotal (1 kit) | Subtotal (60 kits)
IC1/U$1/JP4 | 1x4 Header (Female) | 3 | PTH | PIN1x4 | Digikey | S1012E-04-ND | 1.7 | 102 | 5.1 | 306
K1 | 2x20 Header (Female) | 1 | PTH | PIN2x20 | Digikey | S6104-ND | 3.73 | 223.8 | 3.73 | 223.8
R1 | 1kΩ Resistor | 1 | 1206 | 1kΩ | Digikey
R4,R5 | 3.9kΩ Resistor | 2 | PTH | 3.9kΩ | Digikey | CF14JT3K90CT-ND | 0.6 | 36 | 1.2 | 72
R6,R7 | 4.7kΩ Resistor | 2 | PTH | 4.7kΩ | Digikey | CF14JT4K70CT-ND | 0.45 | 27 | 0.9 | 54
R9 | 1kΩ Resistor | 1 | PTH | 1kΩ | Digikey | CF14JT1K00CT-ND | 0.15 | 9 | 0.15 | 9
D2 | Two colour LED | 1 | PTH | 3mm | Digikey | 1497-1025-ND | 0.61 | 36.6 | 0.61 | 36.6
Q1,Q2 | N-Channel Logic Level MOSFET | 2 | TO-92 | 2N7000 | Creatron | TRFET-007000 | 1.5 | 90 | 3 | 180
IC1 | Real Time Clock (I2C) ZS-042 | 1 | Breakout | DS3231 | Creatron | PRORT-003231 | 11.95 | 717 | 11.95 | 717
U$1 | 8-bit I2C ADC&DAC w/ sensors (YL-40) | 1 | Breakout | PCF8591 | Creatron | PRODA-008591 | 8.5 | 510 | 8.5 | 510
JP4 | BME280 Breakout (3.3V) | 1 | Breakout | BME280 | Sparkfun | SEN-13676
BME header | 1x4 Header (Male 90 degree) | 1 | if not supplied with each breakout
Case | Clear Acrylic 12"x24" |  |  |  | Johnson Industrial |  | 7.18 per sheet fitting 10 units? (case still being designed) |  |  |  | http://www.johnstonplastics.com/toronto/
Screws | Fasteners for case
Laser | Acrylic cutting at a dollar per minute |  |  |  |  |  | $1.75
PCB | Printed Circuit Board | 1 |  |  |  |  | $3.00?
Solder | 1lb 0.032" lead free solder |  |  |  | Mouser | 738-13949 | $96.11 | 1.5 meters per project, 100 meters per spool?
 |  |  |  |  |  | Incomplete Total |  |  | 35.14 | 2108.4

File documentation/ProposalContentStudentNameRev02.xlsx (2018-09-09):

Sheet: DataEntry
Submission Date | YYYY-MM-DD
Project Name | SensorEffector
Student Name | First Last
Project repository | https://github.com/publicusername/SensorEffector
SensorEffector choice
The database will store
The mobile device functionality will include
I will be collaborating with the following company/department
My group in the winter semester will include
50 word problem statement
100 words of background
Current product APA citation
Existing research IEEE paper APA citation
Brief description of planned purchases
Solution description

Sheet: DataBase
Submission Date | Project Name | Student Name | Project repository | SensorEffector choice | The database will store | The mobile device functionality will include | I will be collaborating with the following company/department | My group in the winter semester will include | 50 word problem statement | 100 words of background | Current product APA citation | Existing research IEEE paper APA citation | Brief description of planned purchases | Solution description
YYYY-MM-DD | SensorEffector | First Last | https://github.com/publicusername/SensorEffector | 0 | 0 | 0 | 0 | 0 | 0 | 0 | 0 | 0 | 0 | 0

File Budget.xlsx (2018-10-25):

Malin Lomax | CENG317 Budget
Item | Site | Price
Raspberry Pi 3 | https://www.creatroninc.com/product/raspberry-pi-3-model-b/ | $54.50
Power Supply | https://www.creatroninc.com/product/51v-25a-micro-usb-switching-power-supply/ | $14.75
TMP006 IR Temperature Sensor | https://www.creatroninc.com/product/tmp006-ir-non-contact-temperature-sensor-40c-to-125c/ | $16.85
Jumper Wires Male to Female | https://www.creatroninc.com/product/12-m-f-jumper-wire-10-pack/ | $4.48
Raspberry Pi Case | https://www.creatroninc.com/product/case-for-raspberry-pi-3-transparent/ | $9.99
USB to Ethernet Adapter | https://www.canadacomputers.com/product_info.php?cPath=27_1048_1051&item_id=089634 | $17.99
SD Card w/ Adapter | https://www.canadacomputers.com/product_info.php?cPath=11_1216_175_177&item_id=121310 | $12.99
Total |  | $131.55
Parts I Already Have
Parts Kit
Ethernet Cable
PCB Board
Soldering Iron

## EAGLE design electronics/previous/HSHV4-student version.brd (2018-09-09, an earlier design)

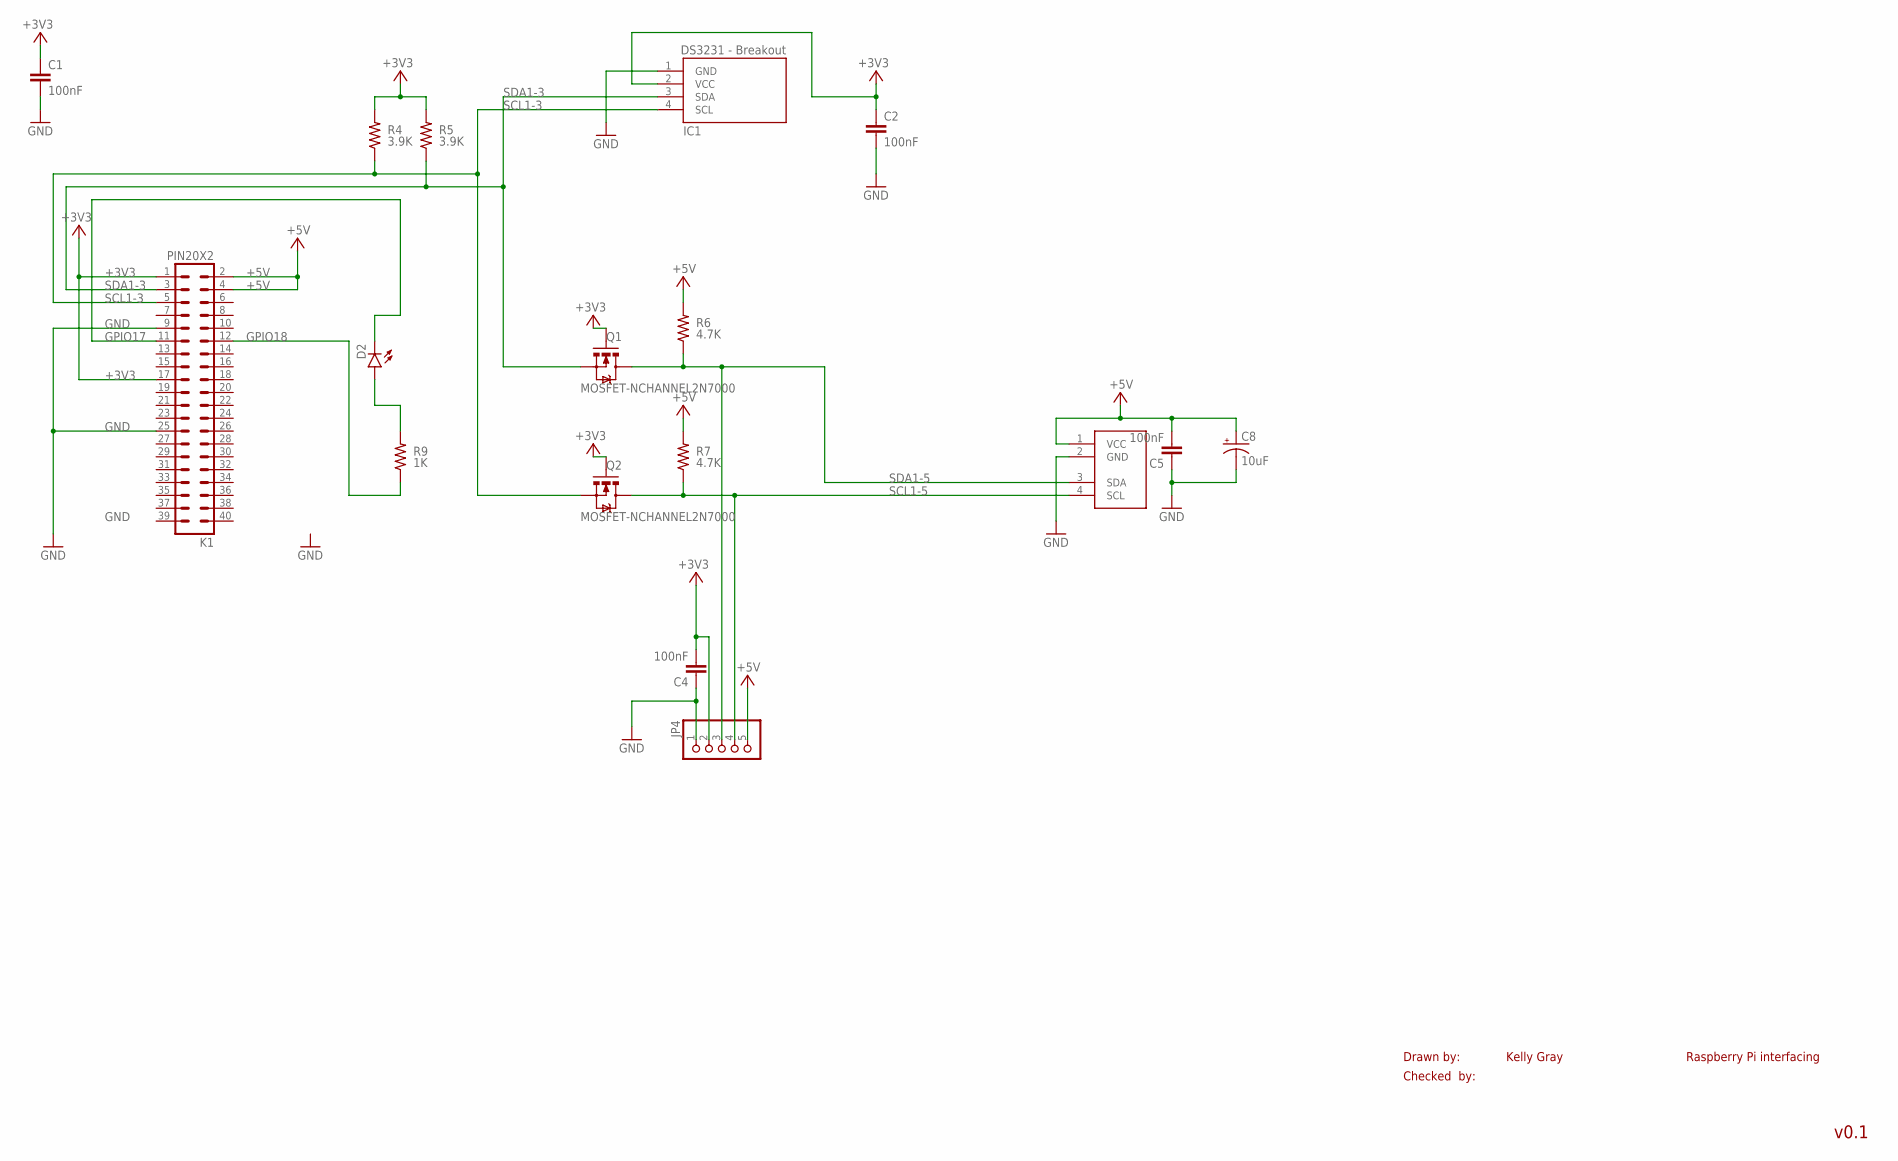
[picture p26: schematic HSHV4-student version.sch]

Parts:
C1, C2, C4, C5: 100nF; CAP-PTH-SMALL-KIT
C8: 10uF; CPOL-RADIAL-10UF-25V
D2: LED-3MM-NO_SILK; LED3MM-NS
IC1: DS3231; 8PTH
JP4: PINHD-1X5; 1X05
K1: PIN20X2; PIN_20X2
Q1, Q2: MOSFET-NCHANNEL2N7000; TO-92
R4, R5: 3.9K; AXIAL-0.3; TOLERANCE 5%
R6, R7: 4.7K; AXIAL-0.3; TOLERANCE 5%
R9: 1K; AXIAL-0.3; TOLERANCE 5%
U$1: PCF8591; 1X04

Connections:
+3V3: C1.1, C2.1, C4.2, IC1.2 (VCC), JP4.2, K1.1, K1.17, Q1.2 (G), Q2.2 (G), R4.P$2 (2), R5.P$2 (2)
+5V: C5.2, C8.1 (+), JP4.5, K1.2, K1.4, R6.P$2 (2), R7.P$2 (2), U$1.1 (VCC)
GND: C1.2, C2.2, C4.1, C5.1, C8.2 (-), IC1.1 (GND), JP4.1, K1.9, K1.25, U$1.2 (GND)
GPIO17: D2.K (C), K1.11
GPIO18: K1.12, R9.P$1 (1)
unnamed: D2.A, R9.P$2 (2)
SCL1-3: IC1.4 (SCL), K1.5, Q2.1 (S), R4.P$1 (1)
SCL1-5: JP4.4, Q2.3 (D), R7.P$1 (1), U$1.4 (SCL)
SDA1-3: IC1.3 (SDA), K1.3, Q1.1 (S), R5.P$1 (1)
SDA1-5: JP4.3, Q1.3 (D), R6.P$1 (1), U$1.3 (SDA)

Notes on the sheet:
Drawn by:
Checked by:
Kelly Gray
v0.1
Raspberry Pi interfacing

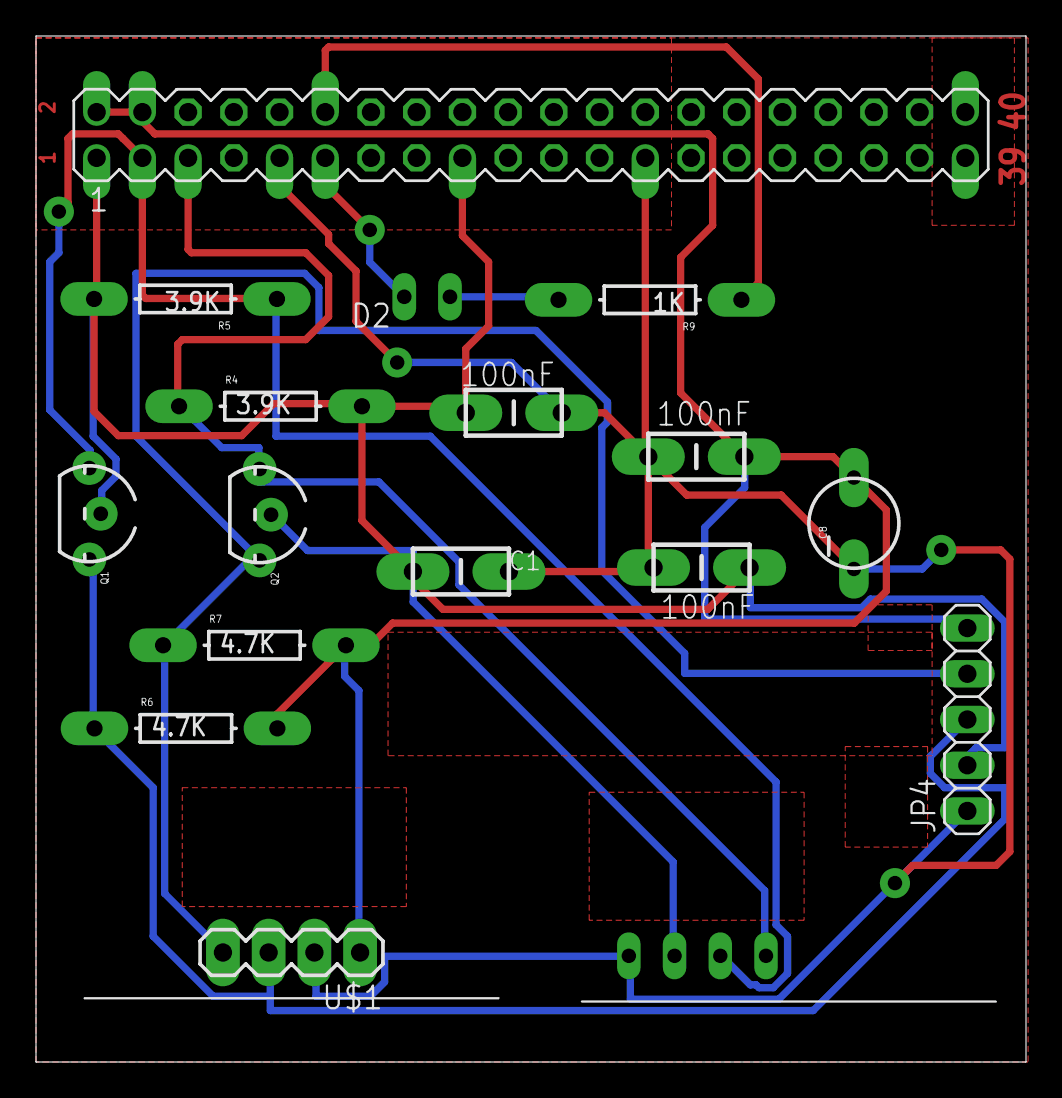
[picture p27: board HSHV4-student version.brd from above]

Board: 2 copper layers, 55.0 x 57.0 mm, 17 parts (0 on the bottom side), 10 nets.

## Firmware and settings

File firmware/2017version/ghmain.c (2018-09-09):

// lab05b.c : Defines the entry point for the console application.
#include <stdio.h>
//#include <stdlib.h>
#include <time.h>
#include "ghcontrol.h"
#include "ghutils.h"
#include "hshbme280.h"
#include <wiringPi.h>
//#include <pcf8591.h>

int main(void)
{
	//Initialization Section
	srand((unsigned) time(NULL));
	if(GhControllerInit()==ABNORMAL)
		GhControllerShutdown(ABNORMAL);
	//GhSetSetpoints();
	time_t current;
	double creadings[SENSORS]={0.0,0.0,0.0,0.0};

	reading_s creading_s = {0};
	setpoint_s sets = {0};
	control_s ctrl = {0};
	alarmlimit_s alimits = {0};

	int tempc;
	int humidc;
	int lightc;

	// Control Loop - FIRST SET OF READINGS ARE NOT CORRECT
	while (1)
	{
		pinMode(HSH_PCF8591_PINBASE, OUTPUT);
		analogWrite(HSH_PCF8591_PINBASE,0);
		delay(1000);
		analogWrite(HSH_PCF8591_PINBASE,127);
		pinMode(HSH_PCF8591_PINBASE, INPUT);
		
		printf("Greenhouse Control Loop");

		//GhGetReadings(&current,creadings);
		creading_s = GhGetReadings();
		creadings[TEMPERATURE]=creading_s.temperature;
		creadings[HUMIDITY]=creading_s.humidity;
		creadings[PRESSURE]=creading_s.pressure;
		creadings[LIGHT]=creading_s.light;
		GhDisplayReadings(&current,creadings);

		//logged = GhLogData("ghdata.txt", creadings);
		//alimits = GhSetAlarmLimits();
		//arecord = GhSetAlarms(arecord,alimits,creadings);

		sets = GhSetSetpoint();
		GhDisplaySetpoints();

		//GhSetControls(&tempc,&humidc,&lightc,creadings);
		ctrl = GhSetControls(sets, creading_s);
		//GhDisplayControls(&tempc,&humidc,&lightc);
		GhDisplayControls(&ctrl.heater,&ctrl.humidifier,&ctrl.light);

		printf("Delaying %d seconds prior to repeating\n\n",UPDATE/1000);
		//if(digitalRead (HSH_MCP23017_PINBASE+GHCOFF))
		//	break;
		GhDelay(UPDATE);
	}
	//printf("\nPress enter to exit");
	//getchar();
	return GhControllerShutdown(NORMAL);
}

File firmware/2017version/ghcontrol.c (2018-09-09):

#include <stdio.h>
#include <stdlib.h>
#include <time.h>
#include <wiringPi.h>
#include "ghcontrol.h"
#include "ghutils.h"
#include "hshbme280.h"
const char alarmnames[NALARMS][ALARMNMSZ] = {"No Alarms","High Temperature", "Low Temperature", "High Humidity",
"Low Humidity", "High Light", "High Pressure", "Low Pressure"};

int GhControllerInit(void)
{
	wiringPiSetup();

	mcp23017Setup(HSH_MCP23017_PINBASE, HSH_MCP23017_I2CADR);
	pcf8591Setup(HSH_PCF8591_PINBASE, HSH_PCF8591_I2CADR);
    BME280Setup();
	// Setup Control Indicators
	pinMode(HSH_MCP23017_PINBASE+HEATERON, OUTPUT);
	pinMode(HSH_MCP23017_PINBASE+HUMIDIFIERON, OUTPUT);
	pinMode(HSH_MCP23017_PINBASE+GHCOFF, INPUT);

    SetLED(GREEN);

	return NORMAL;
}

int GhControllerShutdown(int status)
{
	digitalWrite(HSH_MCP23017_PINBASE+HEATERON, 0);
	digitalWrite(HSH_MCP23017_PINBASE+HUMIDIFIERON, 0);

	if(!status)
	{
		SetLED(RED);
	} else {
		SetLED(NOCOLOUR);
	}
}

reading_s GhGetReadings(void)
{
    reading_s now = {0};

    now.rtime = time(NULL);
    now.temperature = GhGetTemperature();
    now.humidity = GhGetHumidity();
    now.pressure = GhGetPressure();
    now.light = GhGetLight();
    return now;
}

setpoint_s GhSetSetpoint(void)
{
    setpoint_s cpoints = {0};
    cpoints = GhRetrieveSetpoints("setpoints.dat");
    if(cpoints.temperature == 0)
    {
        cpoints.temperature = CTEMP;
        cpoints.humidity = CHUMID;
        cpoints.light = CLIGHT;
        GhSaveSetpoints("setpoints.dat", cpoints);
    }
    return cpoints;
}

control_s GhSetControls(setpoint_s target, reading_s rdata)
{
    control_s cset;
    if(rdata.temperature < target.temperature)
    {
        cset.heater = 1;
        digitalWrite(HSH_MCP23017_PINBASE+HEATERON, 1);
    } else {
        cset.heater = 0;
        digitalWrite(HSH_MCP23017_PINBASE+HEATERON, 0);
    }
    if(rdata.humidity < target.humidity)
    {
        cset.humidifier = 1;
        digitalWrite(HSH_MCP23017_PINBASE+HUMIDIFIERON, 1);
    } else {
        cset.humidifier = 0;
        digitalWrite(HSH_MCP23017_PINBASE+HUMIDIFIERON, 0);
    }
    if(rdata.light <= target.light)
    {
        cset.light = target.light - rdata.light;
    }
    return cset;

}

alarmlimit_s GhSetAlarmLimits(void)
{
    alarmlimit_s calarm;
    calarm.hight = UPPERATEMP;
    calarm.lowt = LOWERATEMP;
    calarm.highh = UPPERAHUMID;
    calarm.lowh = LOWERAHUMID;
    calarm.highl = UPPERALIGHT;
    calarm.lowl = LOWERAHUMID;
    calarm.highp = UPPERAPRESS;
    calarm.lowp = LOWERAPRESS;
    return calarm;
}

int GhSetOneAlarm(alarm_e code, time_t atime, double value, alarm_s * head)
{
    alarm_s * last;
    alarm_s * cur;

    cur = head;
    if(cur->code != 0)
    {
        while(cur !=  NULL)
        {
            if(cur->code == code)
            {
                return 0;
            }
            last = cur;
            cur = cur->next;
        }
        cur = (alarm_s *)calloc(1, sizeof(alarm_s));
        last->next = cur;
        if(cur == NULL)
        {
            return 0;
        }
    }
    cur->code = code;
    cur->atime = atime;
    cur->value = value;
    cur->next = NULL;
    return 1;
}

alarm_s * GhClearOneAlarm(alarm_e code, alarm_s * head)
{
    alarm_s * cur;
    alarm_s * last = NULL;
    cur = last = head;

    if(cur->code == code && cur->next == NULL)
    {
        cur->code = NOALARM;
        return head;
    }

    if(cur-> code == code && cur->next != NULL)
    {
        head = cur->next;
        free(cur);
        return head;
    }

    while(cur != NULL)
    {
        if(cur->code == code)
        {
            last->next = cur->next;
            free(cur);
        }
        last = cur;
        cur = cur->next;
    }
    return head;
}

alarm_s * GhSetAlarms(alarm_s * head, alarmlimit_s alarmpt, reading_s rdata)
{

    if(rdata.temperature >= alarmpt.hight)
    {
        GhSetOneAlarm(HTEMP,rdata.rtime,rdata.temperature,head);
    }
    else
    {
        head = GhClearOneAlarm(HTEMP,head);
    }
    return head;
    if(rdata.temperature <= alarmpt.lowt)
    {
        GhSetOneAlarm(LTEMP,rdata.rtime,rdata.temperature,head);
    }
    else
    {
        head = GhClearOneAlarm(LTEMP,head);
    }
    return head;
    if(rdata.humidity >= alarmpt.highh)
    {
        GhSetOneAlarm(HHUMID,rdata.rtime,rdata.humidity,head);
    }
    else
    {
        head = GhClearOneAlarm(HHUMID,head);
    }
    return head;
    if(rdata.humidity <= alarmpt.lowh)
    {
        GhSetOneAlarm(LHUMID,rdata.rtime,rdata.humidity,head);
    }
    else
    {
        head = GhClearOneAlarm(LHUMID, head);
    }

    if(rdata.light >= alarmpt.highl)
    {
        GhSetOneAlarm(HLIGHT,rdata.rtime,rdata.light,head);
    }
    else
    {
        head = GhClearOneAlarm(HLIGHT,head);
    }
    return head;
    if(rdata.light <= alarmpt.lowl)
    {
        GhSetOneAlarm(LLIGHT,rdata.rtime,rdata.light,head);
    }
    else
    {
        head = GhClearOneAlarm(LLIGHT,head);
    }
    return head;
    if(rdata.pressure >= alarmpt.highp)
    {
        GhSetOneAlarm(HPRESS,rdata.rtime,rdata.pressure,head);
    }
    else
    {
        head = GhClearOneAlarm(HPRESS,head);
    }
    return head;
    if(rdata.pressure <= alarmpt.lowp)
    {
        GhSetOneAlarm(LPRESS,rdata.rtime,rdata.pressure,head);
    }
    else
    {
        head = GhClearOneAlarm(HTEMP,head);
    }
    return head;
}

double GhGetTemperature(void)
{
    #if SIMTEMPERATURE
        return GetRandom((UPPERATEMP - LOWERATEMP) + LOWERATEMP);
    #else
        //return GetBME280TempC();
		return analogRead(HSH_PCF8591_PINBASE+HSH_PCF8591_A1IN)-186.0;
    #endif

}

double GhGetHumidity(void)
{
    #if SIMHUMIDITY
        return GetRandom((UPPERAHUMID - LOWERAHUMID) + LOWERAHUMID);
    #else
        return GetBME280Humidity();
    #endif // SIMHUMIDITY
}

double GhGetPressure(void)
{
    #if SIMPRESSURE
        return GetRandom((UPPERAPRESS - LOWERAPRESS) + LOWERAPRESS);
    #else
        return PaTomB(GetBME280Pressure());
    #endif // SIMPRESSURE
}

double GhGetLight(void)
{
    #if SIMLIGHT
        return 125;
    #else
        return 255-analogRead(HSH_PCF8591_PINBASE+HSH_PCF8591_A0IN);
    #endif // SIMLIGHT
}

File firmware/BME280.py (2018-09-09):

#!/usr/bin/python
#
# Reference: Matt Hawkins's Code on
# http://www.raspberrypi-spy.co.uk/

# Revised by Austin Tian 
#--------------------------------------
import smbus
import time
from ctypes import c_short
from ctypes import c_byte
from ctypes import c_ubyte
from time import sleep

DEVICE = 0x77 # Default device I2C address
BME280_DEVICE = 0x77 # BME280 I2C address
YL40_DEVICE = 0x48  # YL-40 I2C address
YL40_DEVICE_MASK = 0x40

#Initialize the Pi 
bus = smbus.SMBus(1) # Rev 2 Pi, Pi 2 & Pi 3 uses bus 1
                     # Rev 1 Pi uses bus 0

#Some data conversion functions from registers. 
def getShort(data, index):
  # return two bytes from data as a signed 16-bit value
  return c_short((data[index+1] << 8) + data[index]).value

def getUShort(data, index):
  # return two bytes from data as an unsigned 16-bit value
  return (data[index+1] << 8) + data[index]

def getChar(data,index):
  # return one byte from data as a signed char
  result = data[index]
  if result > 127:
    result -= 256
  return result

def getUChar(data,index):
  # return one byte from data as an unsigned char
  result =  data[index] & 0xFF
  return result

#The foolowing code is for AD YL-40 PCF8591 board. 
#==========================================================================
def readYL40Analog(addr=YL40_DEVICE): 
  return_list = []
  aout = 0
  for a in range(0,4):
    bus.write_byte_data(YL40_DEVICE, 0x40+a, aout)    
    read_value = bus.read_byte(YL40_DEVICE) # This is the data from A/D channel.
    read_value = bus.read_byte(YL40_DEVICE) # Read Twice to get the current data. 
    return_list.append(read_value)
    aout = aout + 1
  return return_list

#The following code is for DA of YL-40 PCF8591 board. 
#==========================================================================
def writeYL40Digital(addr=YL40_DEVICE, digital_data=0): 
    bus.write_byte_data(addr, 0x41, digital_data)  # 0x41 is the D/A channel. 
    return

#The foolowing code is for BME280 board. 
#==========================================================================
def readBME280ID(addr=BME280_DEVICE):
  # Chip ID Register Address
  REG_ID     = 0xD0
  (chip_id, chip_version) = bus.read_i2c_block_data(addr, REG_ID, 2)
  return (chip_id, chip_version)

#Read Data from different registers on BME280 and calculate the Temperature, Humidity and Pressure.
def readBME280All(addr=BME280_DEVICE):   
  # Register Addresses
  REG_DATA = 0xF7
  REG_CONTROL = 0xF4
  REG_CONFIG  = 0xF5

  REG_CONTROL_HUM = 0xF2
  REG_HUM_MSB = 0xFD
  REG_HUM_LSB = 0xFE

  # Oversample setting - page 27
  OVERSAMPLE_TEMP = 2
  OVERSAMPLE_PRES = 2
  MODE = 1

  # Oversample setting for humidity register - page 26
  OVERSAMPLE_HUM = 2
  bus.write_byte_data(addr, REG_CONTROL_HUM, OVERSAMPLE_HUM)

  control = OVERSAMPLE_TEMP<<5 | OVERSAMPLE_PRES<<2 | MODE
  bus.write_byte_data(addr, REG_CONTROL, control)

  # Read blocks of calibration data from EEPROM
  # See Page 22 data sheet
  cal1 = bus.read_i2c_block_data(addr, 0x88, 24)
  cal2 = bus.read_i2c_block_data(addr, 0xA1, 1)
  cal3 = bus.read_i2c_block_data(addr, 0xE1, 7)

  # Convert byte data to word values
  # Read Temperature
  dig_T1 = getUShort(cal1, 0)
  dig_T2 = getShort(cal1, 2)
  dig_T3 = getShort(cal1, 4)
  # Read Pressure
  dig_P1 = getUShort(cal1, 6)
  dig_P2 = getShort(cal1, 8)
  dig_P3 = getShort(cal1, 10)
  dig_P4 = getShort(cal1, 12)
  dig_P5 = getShort(cal1, 14)
  dig_P6 = getShort(cal1, 16)
  dig_P7 = getShort(cal1, 18)
  dig_P8 = getShort(cal1, 20)
  dig_P9 = getShort(cal1, 22)
  # Read Humidity
  dig_H1 = getUChar(cal2, 0)
  dig_H2 = getShort(cal3, 0)
  dig_H3 = getUChar(cal3, 2)

  dig_H4 = getChar(cal3, 3)
  dig_H4 = (dig_H4 << 24) >> 20
  dig_H4 = dig_H4 | (getChar(cal3, 4) & 0x0F)

  dig_H5 = getChar(cal3, 5)
  dig_H5 = (dig_H5 << 24) >> 20
  dig_H5 = dig_H5 | (getUChar(cal3, 4) >> 4 & 0x0F)

  dig_H6 = getChar(cal3, 6)

  # Wait in ms (Datasheet Appendix B: Measurement time and current calculation)
  wait_time = 1.25 + (2.3 * OVERSAMPLE_TEMP) + ((2.3 * OVERSAMPLE_PRES) + 0.575) + ((2.3 * OVERSAMPLE_HUM)+0.575)
  time.sleep(wait_time/1000)  # Wait the required time  

  # Read temperature/pressure/humidity
  data = bus.read_i2c_block_data(addr, REG_DATA, 8)
  pres_raw = (data[0] << 12) | (data[1] << 4) | (data[2] >> 4)
  temp_raw = (data[3] << 12) | (data[4] << 4) | (data[5] >> 4)
  hum_raw = (data[6] << 8) | data[7]

  #Refine temperature
  var1 = ((((temp_raw>>3)-(dig_T1<<1)))*(dig_T2)) >> 11
  var2 = (((((temp_raw>>4) - (dig_T1)) * ((temp_raw>>4) - (dig_T1))) >> 12) * (dig_T3)) >> 14
  t_fine = var1+var2
  temperature = float(((t_fine * 5) + 128) >> 8);

  # Refine pressure and adjust for temperature
  var1 = t_fine / 2.0 - 64000.0
  var2 = var1 * var1 * dig_P6 / 32768.0
  var2 = var2 + var1 * dig_P5 * 2.0
  var2 = var2 / 4.0 + dig_P4 * 65536.0
  var1 = (dig_P3 * var1 * var1 / 524288.0 + dig_P2 * var1) / 524288.0
  var1 = (1.0 + var1 / 32768.0) * dig_P1
  if var1 == 0:
    pressure=0
  else:
    pressure = 1048576.0 - pres_raw
    pressure = ((pressure - var2 / 4096.0) * 6250.0) / var1
    var1 = dig_P9 * pressure * pressure / 2147483648.0
    var2 = pressure * dig_P8 / 32768.0
    pressure = pressure + (var1 + var2 + dig_P7) / 16.0

  # Refine humidity
  humidity = t_fine - 76800.0
  humidity = (hum_raw - (dig_H4 * 64.0 + dig_H5 / 16384.0 * humidity)) * (dig_H2 / 65536.0 * (1.0 + dig_H6 / 67108864.0 * humidity * (1.0 + dig_H3 / 67108864.0 * humidity)))
  humidity = humidity * (1.0 - dig_H1 * humidity / 524288.0)
  if humidity > 100:
    humidity = 100
  elif humidity < 0:
    humidity = 0

  return temperature/100.0,pressure/100.0,humidity

#Reset the BME280 board at the beginning of program. 
def ResetBME280Sensors(addr=BME280_DEVICE):
  REG_RESET = 0xE0 # Reset Register Address
  bus.write_byte_data(addr, REG_RESET, 0xB6)
  return bus.read_i2c_block_data(addr, REG_RESET, 1)
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

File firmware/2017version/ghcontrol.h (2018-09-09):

// Function headers for ghcontrol.c

#ifndef GHCONTROL_H
	#define GHCONTROL_H

	// CONSTANTS
	#define UPDATE 1000
	#define SENSORS 4
	#define TEMPERATURE 0
	#define HUMIDITY 1
	#define PRESSURE 2
	#define LIGHT 3

	#define NALARMS 9
    #define NOALARMS 0
    #define ALARMNMSZ 18

	// Sense Hat pinbase
	#define HSH_RTC_I2CADR 0x68
	#define HSH_MCP23017_I2CADR 0x20
	#define HSH_PCF8591_I2CADR 0x48
	#define HSH_BME280_I2CADR 0x76
	#define HSH_MCP23017_PINBASE 100
	#define HSH_PCF8591_PINBASE 200
	#define HSH_BME280_PINBASE 300
	//#define HSH_PCF8591_A0IN 3 //A0 = LDR
	#define HSH_PCF8591_A0IN 0  // AIN0 = PHOTORESISTOR
	#define HSH_PCF8591_A1IN 1  // AIN1 = THERMISTOR
	#define HSH_PCF8591_A2IN 2  // AIN2
	#define HSH_PCF8591_A3IN 3  // AIN3 = POT
	//Aout = D1, VCC=D2
	//printf("Photoresistor: %d\t",analogRead(HSH_PCF8591_PINBASE+HSH_PCF8591_A0IN));
	//printf("Thermistor: %d\n",analogRead(HSH_PCF8591_PINBASE+HSH_PCF8591_A1IN));
	//printf("AIN2: %d\t",analogRead(HSH_PCF8591_PINBASE+HSH_PCF8591_A2IN));
	//printf("Potentiometer: %d\n",analogRead(HSH_PCF8591_PINBASE+HSH_PCF8591_A3IN));


	// Controls
	#define CTEMP 25
	#define CHUMID 55
	#define CLIGHT 255
	#define HEATERON	0
	#define HUMIDIFIERON	1
	#define GHCOFF 2
	#define NORMAL 1
	#define ABNORMAL 0


    // constants
	#define UPPERATEMP 30
	#define LOWERATEMP 10
	#define UPPERAHUMID 70
	#define LOWERAHUMID 25
	#define UPPERAPRESS 1016
	#define LOWERAPRESS 985
	#define UPPERALIGHT 255
	#define LOWERALIGHT 0


    // simulation constants
    #define SIMTEMPERATURE 0
    #define SIMHUMIDITY 0
    #define SIMPRESSURE 0
    #define SIMLIGHT 0

    //reading structure
    typedef struct readings
    {
        time_t rtime;
        double temperature;
        double humidity;
        double pressure;
        double light;
    }reading_s;

    typedef struct setpoints
    {
        double temperature;
        double humidity;
        double light;
    }setpoint_s;

    typedef struct controls
    {
        int heater;
        int humidifier;
        int light;
    }control_s;

    typedef enum { NOALARM, HTEMP, LTEMP, HHUMID, LHUMID, HLIGHT, LLIGHT, HPRESS, LPRESS } alarm_e;

    typedef struct alarmlimits
    {
        double hight;
        double lowt;
        double highh;
        double lowh;
        double highl;
        double lowl;
        double highp;
        double lowp;
    }alarmlimit_s;

    typedef struct alarms
    {
        alarm_e code;
        time_t atime;
        double value;
        struct alarms * next;
    }alarm_s;

	// Function Prototypes
    int GhControllerInit(void);
	double GhGetTemperature(void);
	double GhGetHumidity(void);
	double GhGetPressure(void);
	double GhGetLight(void);
    reading_s GhGetReadings(void);
    setpoint_s GhSetSetpoint(void);
    control_s GhSetControls(setpoint_s target, reading_s rdata);
    alarmlimit_s GhSetAlarmLimits(void);
	alarm_s * GhSetAlarms(alarm_s * head, alarmlimit_s alarmpt, reading_s rdata);
	int GhSetOneAlarm(alarm_e code, time_t atime, double value, alarm_s * head);
    alarm_s * GhClearOneAlarm(alarm_e code, alarm_s * head);
#endif

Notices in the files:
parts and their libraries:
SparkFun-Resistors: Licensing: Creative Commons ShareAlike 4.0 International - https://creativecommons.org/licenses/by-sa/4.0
